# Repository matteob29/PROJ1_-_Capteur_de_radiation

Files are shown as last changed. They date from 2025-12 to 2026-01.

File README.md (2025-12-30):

# PROJ1 – Conception d’un capteur de radiation avec tube Geiger

Projet réalisé dans le cadre du module **PROJ1 – Projet analogique** en première année à l’**ENSEIRB-MATMECA**.

**Auteurs :** 

Mattéo BINET  
Quentin MARIE  

**Date :** 30 décembre 2025  

---

## 1. Introduction

Le projet de conception électronique consiste en l'étude et la réalisation d'un capteur de radiation fonctionnel et compact. Ce système repose sur l'utilisation d'un tube Geiger-Müller J315 pour la détection de particules ionisantes.

L'architecture du circuit est une adaptation modernisée du module CAJOE, transposée en technologie de composants montés en surface (CMS) afin de réduire l'encombrement global. La conception a été intégralement réalisée sous le logiciel de CAO **KiCad E.D.A. 9.0.5**.

---

## 2. Cahier des charges (Tube J315)

- **Type de tube :** Halogène à impulsion pour rayonnements beta et gamma.
- **Tension de travail recommandée :** 380 V.
- **Plage du plateau :** 80 V avec une pente maximale de 10 % / 80 V.
- **Tension d'alimentation :** +5 V DC.
- **Protection :** Fusible de 750 mA intégré pour prévenir les courts-circuits.
- **Consommation nominale :** Environ 40 mA.

---

## 3. Conception du circuit

Le circuit est divisé en quatre blocs fonctionnels principaux :

1. **Module d'Alimentation :**
   - Entrée via connecteur JST XH à trois broches (GND, INT, +5 V).
   - Protection par fusible F1 et filtrage par condensateur de découplage C1 (100 nF).
   - Interrupteur bipolaire SW1 pour la mise hors tension complète.

2. **Étage Boost DC-DC :**
   - Oscillateur basé sur un circuit intégré **NE555** (U1) configuré en mode astable.
   - Élévation de tension par découpage via une inductance L2 (10 mH) et un transistor haute tension **MMBTA42** (Q1).
   - Fréquence d'oscillation fixée à 7059 Hz.

3. **Tripleur de tension :**
   - Structure de type Cockcroft-Walton composée de trois diodes **ES1J** (D2, D3, D4) et de condensateurs haute tension (10 nF / 1000 V).
   - Permet d'atteindre la tension de polarisation théorique de 400 V par effet de pompe de charge.

4. **Détecteur d’impulsion :**
   - Le tube V1 génère une avalanche électronique lors du passage d'une particule.
   - Mise en forme du signal par un second **NE555** (U2) configuré en monostable pour produire une impulsion calibrée de 517 us.
   - Signalisation visuelle par une LED rouge D5 à chaque détection.

---

## 4. Résultats expérimentaux

Les mesures effectuées à l'oscilloscope valident le comportement théorique :

- **Sortie Boost :** Observation de pics de tension d'environ 280 V au nœud boost_dc.
- **Sortie Multiplicateur :** Stabilisation de la haute tension après l'étage de filtrage.
- **Plage de réglage :** Tension de sortie ajustable entre 200 V et 550 V via le potentiomètre RV1, permettant un calage précis à 380 V.

---

## 5. Procédure de réglage

Le réglage de la haute tension s'effectue impérativement sans le tube Geiger :

1. **Mise sous tension :** Alimenter la carte en +5 V et vérifier l'allumage de la LED verte D1.
2. **Mesure :** Placer un voltmètre (calibre 1000 V) entre le point de test "tripleur" et la masse.
3. **Ajustement :** Régler RV1 jusqu'à obtenir 380 V.
4. **Alternative :** Une mesure indirecte est possible au point de test TP_Geiger situé après un pont diviseur de 50 MOhm.

---

## 6. Conclusion

Ce projet a permis de valider la conception d'un compteur Geiger CMS performant. L'intégration des étages de puissance et de détection sur un PCB compact répond aux exigences de fiabilité et de sécurité fixées initialement. Le dispositif constitue une base documentée pour toute application de surveillance radiologique.

---

## 7. Contenu du dépôt GitHub

Le dépôt contient l'intégralité des fichiers nécessaires à la reproduction du projet :

- [Carte_électronique/](./Carte_électronique) -> Schématics, fichiers de routage PCB et modèles 3D Kicad
- [Composants/](./Composants) -> Lien des sites utiles
- [Datasheet/](./Datasheet) -> Fiches techniques des composants critiques (NE555, MMBTA42, J315)
- [code_J315/](./code_J315) -> Exemple de code Arduino pour le comptage des impulsions (PPS)
- [README.md](./README.md) -> Présentation du projet

---

© 2025 — Mattéo BINET, Quentin MARIE
Département Électronique — PROJ1
Enseirb-Matmeca — Capteur de rayonnement beta & gamma

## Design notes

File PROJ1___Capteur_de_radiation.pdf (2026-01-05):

# Capteur de radiation avec tube Geiger

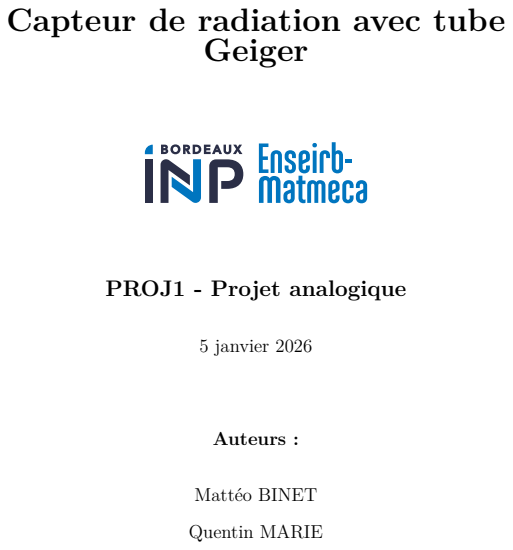
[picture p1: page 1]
PROJ1 - Projet analogique; 5 janvier 2026; Auteurs :; Mattéo BINET; Quentin MARIE

## Sommaire

Introduction | 1
1 Principe de la détection de radiation | 1
2 Étude et conception du circuit | 4
3 Étude et conception du circuit | 8
4 Conclusion | 15
Annexe | 16
Bibliographie | 22

Capteur de radiation avec tube Geiger

## Introduction

La détection des rayonnements ionisants est un enjeu majeur dans de nombreux domaines, allant de la surveillance environnementale à la sécurité nucléaire, en passant par la physique médicale. Dans le cadre de ce projet, nous nous sommes attachés à l’étude, la conception et la réalisation d’un capteur de radiation (compteur Geiger-Müller) fonctionnel et compact.
Pour la conception électronique. Nous avons choisi d’analyser et d’adapter l’architecture du kit CAJOE en cms. L’enjeu technique a consisté à comprendre les différents blocs de ce système, notamment la gestion de la Haute Tension nécessaire au tube pour ensuite proposer notre propre implémentation.
Le travail a été réalisé sous le logiciel de CAO KiCad. Il a fallu saisir le schématique, choisir des composants adaptés et réaliser le routage de la carte en respectant les contraintes de place et de routage.
Ce compte rendu détaille notre démarche : il présente d’abord le principe physique du tube Geiger J315, puis l’analyse du schéma électronique inspiré du module CAJOE, et enfin la description technique des différents étages de la carte réalisée.

## 1 Principe de la détection de radiation

### 1.1 Rôle d’un tube Geiger

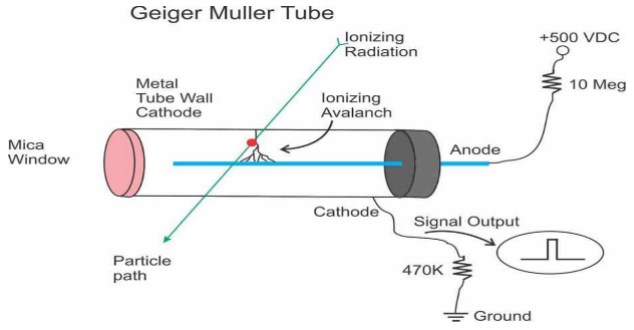
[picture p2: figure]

Figure 1 – Schématique de principe et fonctionnement du tube Geiger-Müller

Le capteur de radiation utilise un tube Geiger-Müller. Ce tube est une ampoule scellée qui contient un gaz inerte à basse pression (typiquement un gaz noble comme du néon, de l’argon ou de l’hélium). Sa structure se compose d’une cathode (pôle négatif), généralement l’enveloppe du tube (verre), et d’une anode (pôle positif), constituée d’un fil métallique fin tendu au centre.
Le principe de fonctionnement repose sur l’ionisation par choc du gaz interne. Afin que la détection soit possible, le tube doit être alimenté par un fort potentiel (typiquement entre 300V et 400V). Les particules radioactives n’ayant pas toujours l’énergie suffisante pour ioniser le gaz par elles-mêmes, cette haute tension est nécessaire pour amener le gaz proche de son point de décharge.
Mattéo BINET | 1 | Quentin MARIE

Lorsqu’une particule chargée (rayonnement ionisant) traverse le tube, elle déclenche l’événement en arrachant des électrons aux atomes du gaz. Ces électrons sont fortement accélérés vers l’anode par le champ électrique intense. Sur leur chemin, leur vitesse leur permet d’entrer en collision avec d’autres atomes, les ionisant à leur tour et arrachant de nouveaux électrons. Ce phénomène se répète en cascade, créant une avalanche électronique massive et rapide. L’arrivée de cette vague d’électrons sur l’anode provoque une chute momentanée du potentiel. Cette variation est détectée sous la forme d’une impulsion électrique, qui est ensuite comptabilisée par l’électronique de la carte.

### 1.2 Caractéristiques du tube J315

Les spécifications suivantes pour le tube Geiger J315 sont extraites du référentiel GitHub du fabricant de la carte et d’un vendeur Aliexpress [1], aucune fiche technique officielle du fournisseur n’ayant été trouvée.

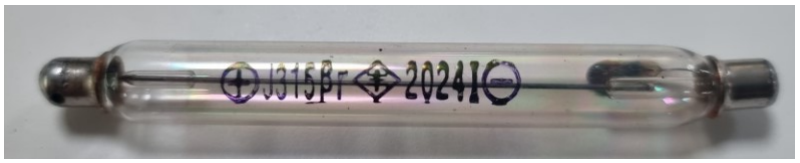
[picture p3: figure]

Figure 2 – Tube Geiger J315

Table 1 – Caractéristiques Techniques Détaillées du Tube Geiger J315

Paramètre | Valeur | Unité
Construction et Dimensions
Type de Tube | Tube halogène à impulsion | –
Matériau de la Cathode | Oxyde d’étain | –
Densité de la Paroi du Tube | 50 ± 10 | cg/cm²
Longueur Totale | 90 ± 2 | mm
Diamètre | 10 ± 0.5 | mm
Masse | 4.5 | g
Performances et Environnement
Plage de Température | −40 à 55 | ◦C
Tension de Démarrage (Vb1 ) | < 350 | V
Tension de Travail Recommandée | 380 | V
Tension de Travail Maximale (Vb2 ) | 550 | V
Longueur Minimale du Plateau | 80 | V
Pente Maximale du Plateau | 10 | %/80V
Taux de Comptage de Fond Max. | 25 | fois/minute
Durée de Vie (Lifetime) | > 1 × 10⁹ | pulses
Mattéo BINET | 2 | Quentin MARIE

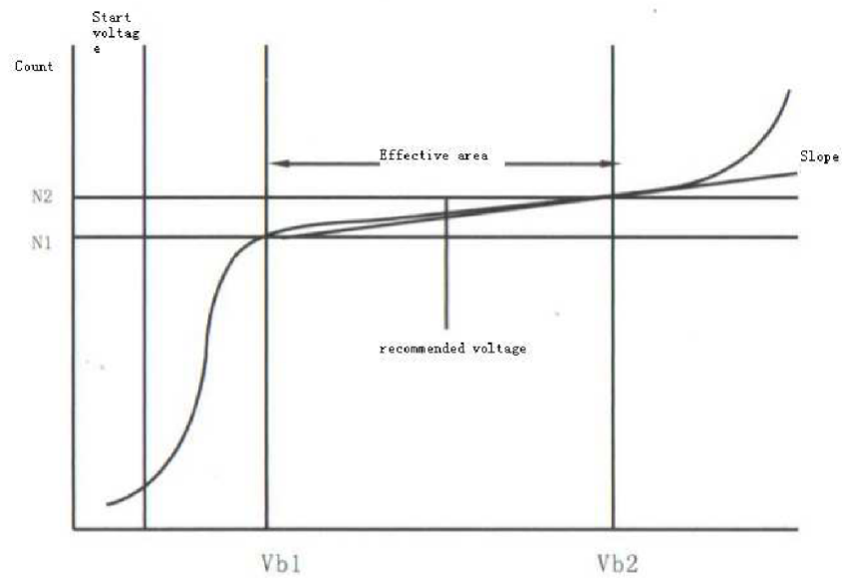
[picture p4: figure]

Figure 3 – Courbe Caractéristique du Plateau

Le graphique en Figure 2 permet de déterminer la tension de travail optimale et stable de notre tube Geiger. Il représente la relation entre le nombre d’impulsions détectées (axe vertical) et la tension appliquée au tube (axe horizontal).

— Tension de Démarrage (Vb1) : Cette tension correspond à la tension minimale où le tube commence à détecter les rayonnements, initiant l’avalanche électronique. Avant cette tension, le champ électrique est insuffisant pour accélérer les électrons.
— Le Plateau (Effective Area) : Situé entre la tension Vb1 et Vb2, il s’agit de la zone de fonctionnement idéale du tube. Dans cette région, l’impulsion détectée est maximale et ne dépend plus de l’énergie de la particule incidente. C’est dans cette plage stable que la tension d’alimentation doit être choisie (Tension de Travail Recommandée).

— La Pente (Slope) : Elle représente la stabilité du tube. Une pente faible indique que le taux de détection est peu sensible aux variations de la tension d’alimentation. — Tension Maximale de Travail (Vb2) : Cette tension marque la limite supérieure du plateau. Au-delà de Vb2, le champ électrique est trop intense et le tube entre en décharge continue car le gaz s’ionise spontanément. Le fonctionnement dans cette zone peut dégrader le tube de manière permanente.

Mattéo BINET | 3 | Quentin MARIE

## 2 Étude et conception du circuit

### 2.1 Architecture du module CAJOE

Le module CAJOE [2] est une plateforme de détection de radiation. Nous l’avons choisi comme référence car il propose une solution robuste et entièrement analogique pour piloter des tubes Geiger-Müller, sans nécessiter de microcontrôleur complexe pour la gestion de la haute tension.
Son architecture s’articule autour de trois blocs fonctionnels distincts, que nous avons reproduits dans notre conception :

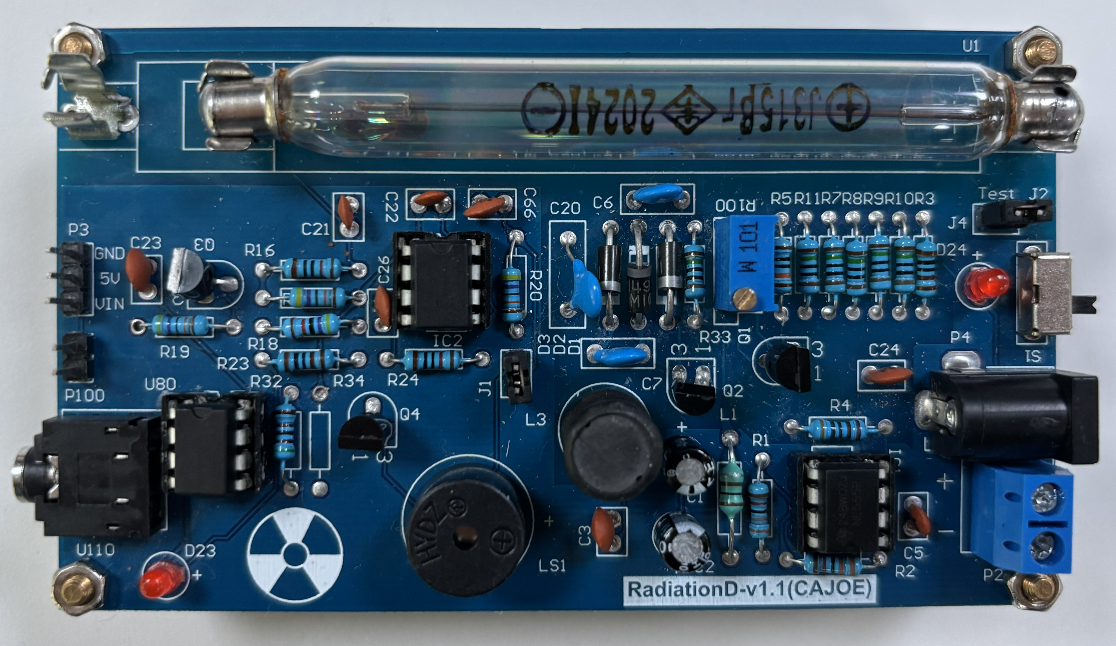
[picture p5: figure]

Figure 4 – Carte électronique du détecteur CAJOE

— La génération de Haute Tension (HV) : Le tube J315 nécessite une tension de polarisation d’environ 400V pour fonctionner dans sa zone de plateau. Le module CAJOE utilise une topologie de convertisseur Boost (élévateur de tension) pilotée par un oscillateur composé d’un NE555. Ce premier étage élève la tension de 5V à une centaine de volts. Cette tension est ensuite amplifiée par un réseau tripleur de tension (pompe de charge) pour atteindre la tension finale requise. La tension de sortie est réglable via le potentiomètre RV1 de 100Ω. Il permet d’ajuster la haute tension sur une plage comprise entre 350V et 450V , assurant ainsi le point de fonctionnement optimal du tube.

— L’interface de détection : Le tube Geiger est un capteur à très haute impédance. Lorsqu’une particule ionise le gaz, une impulsion de courant très faible et brève est générée. L’architecture utilise un étage d’entrée à transistor pour détecter cette variation de potentiel sur la cathode sans perturber la haute tension.

— La mise en forme du signal : Le signal brut issu du tube est souvent bruité et trop court pour être exploité directement par un indicateur visuel. Un étage de sortie, configuré en monostable via un second NE555, permet de calibrer l’impulsion de sortie. Cela garantit un signal carré propre (TTL) d’une durée suffisante pour qu’une LED rouge (témoin lumineux) soit visible par l’œil humain.

Mattéo BINET | 4 | Quentin MARIE

### 2.2 Fonctionnement et utilisation de la carte CMS

Cette version du capteur se distingue des modules CAJOE classiques par une conception modernisée et simplifiée.

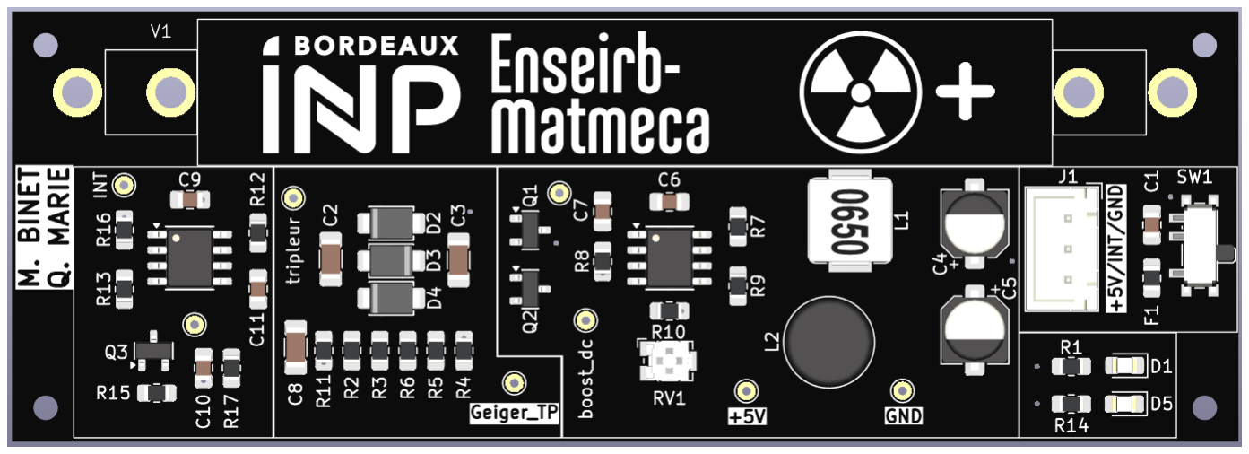
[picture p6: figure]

Figure 5 – Modèle 3D - Carte électronique CMS

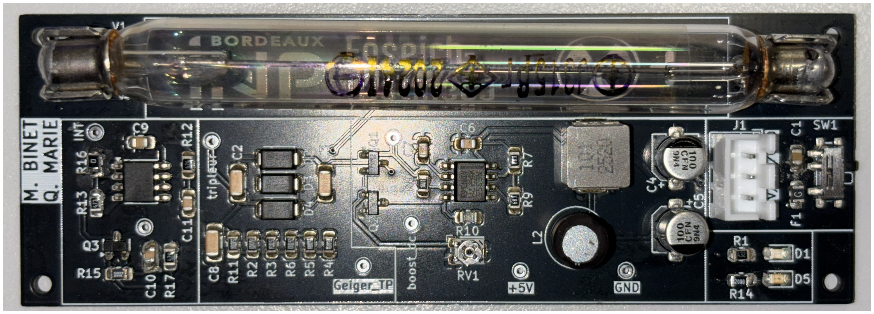
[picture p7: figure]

Figure 6 – Carte électronique CMS

### 2.2.1 Sécurité et Protection

Un ajout majeur par rapport au design d’origine est l’intégration d’un étage de protection en entrée. Un fusible F1 a été placé en série sur la ligne d’alimentation 5V. Il est calibré à 750mA. Ce dimensionnement est volontairement supérieur à la consommation nominale du circuit (≈ 40mA) afin d’éviter tout déclenchement intempestif lors des pics de courant, tout en garantissant une protection efficace et une coupure du circuit en cas de court-circuit franc sur la carte.

### 2.2.2 Comparatif : Module CAJOE vs Carte CMS

Le tableau ci-dessous met en évidence les différences structurelles et fonctionnelles entre le module du commerce et notre réalisation.

Mattéo BINET | 5 | Quentin MARIE

Table 2 – Comparaison entre le module CAJOE standard et la carte CMS réalisée

Caractéristique | Module CAJOE (Réf) | Carte CMS (Projet)
Technologie | THT | CMS
Connectique | Bornier, DC, Dupont | JST XH 3 pins
Interface Audio | Jack 3.5mm + Haut-parleur | Ø
Protection | Ø | Fusible 750mA
Architecture | AOP LM358 + NE555 | NE555 uniquement
Tension d’alimentation | +5V | +5V
Courant nominal d’alimentation | 20-40mA | 20-40mA
Poids avec tube | 47.3g | 19.0g
Longueur | 108mm | 100mm
Largeur | 62, 8mm | 35mm
trou de fixation | M3 | M2

### 2.2.3 Procédure de réglage

Le réglage de la haute tension est une étape critique qui doit être réalisée avant l’installation du tube.

1. Préparation : S’assurer que le tube Geiger J315 est débranché de son support.
2. Alimentation : Connecter l’alimentation (+5V et GND) au connecteur JST. Une LED verte (D1 : témoin d’alimentation) doit normalement s’allumer. Si ce n’est pas le cas, vérifier que le kill switch (SW1) est en position haute.

Méthodes de calibration : Il existe deux méthodes pour ajuster le potentiomètre RV1 afin d’atteindre la tension de plateau du tube (380V).

— Méthode 1 : Mesure directe
Cette méthode consiste à mesurer la tension réelle en sortie du multiplicateur.
— Placer le voltmètre (calibre 1000V DC) entre la masse (GND) et le point de test tripleur.
— Ajuster RV1 jusqu’à lire 380V.
— Attention : S’assurer que le multimètre supporte cette tension élevée.

— Méthode 2 : Mesure indirecte
Cette méthode utilise le point de test TP_Geiger (ou TP3) situé après un pont diviseur résistif de 50MΩ (5×10MΩ). La lecture dépendra fortement de l’impédance d’entrée de votre multimètre (effet de charge) :

— Avec un multimètre standard (impédance 1 MΩ) : Régler RV1 pour obtenir environ 6,5V.
— Avec un multimètre haute impédance (impédance 10 MΩ) : Régler RV1 pour obtenir environ 65V.

Une fois le réglage effectué, couper l’alimentation avant d’insérer le tube J315.

Mattéo BINET | 6 | Quentin MARIE

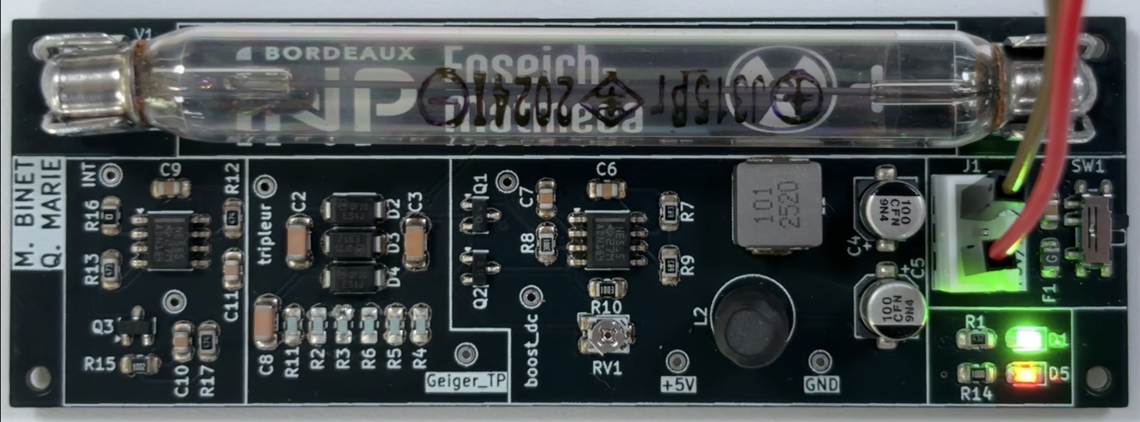
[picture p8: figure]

Figure 7 – Carte électronique en fonctionnement

### 2.3 Utilisation

Le capteur de radiation peut être exploité de deux manières. D’une part, les données peuvent être récupérées via une carte d’acquisition telle qu’une Arduino ou une ESP, en utilisant la broche INT disponible sur le connecteur JST. Cette sortie est maintenue à un niveau logique haut (environ 5 V) au repos et génère une impulsion à 0 V à chaque détection d’une particule par le tube Geiger J315. Le signal étant actif bas, il peut être lu efficacement à l’aide d’une interruption matérielle afin de compter précisément les événements détectés.
Un exemple de code utilisé pour compter le nombre d’impulsions détectées sur la dernière seconde (PPS – Pulses Per Second) à l’aide d’une carte Arduino Nano est présenté ci-dessous.

Listing 1 – Comptage des impulsions Geiger en PPS

# define GEIGER_PIN 2

volatile unsigned long pulseCount = 0; unsigned long lastSecond = 0; unsigned long pps = 0;

void geigerISR () {
pulseCount ++;

}

void setup () {
Serial . begin (115200) ;
while (! Serial ) ;

pinMode ( GEIGER_PIN , INPUT_PULLUP ) ;
attachInterrupt ( digitalPinToInterrupt ( GEIGER_PIN ) , geigerISR , FALLING ) ;

lastSecond = millis () ;

}

void loop () {

Mattéo BINET | 7 | Quentin MARIE

23 if ( millis () - lastSecond >= 1000) {

24
25 | noInterrupts () ;
26 | pps = pulseCount ;
27 | pulseCount = 0;
28 | interrupts () ;

29
30 | Serial . print ("PPS = ") ;
31 | Serial . println ( pps ) ;

32
33 | lastSecond += 1000;
34 | }
35 | }

D’autre part, la carte intègre une LED rouge (D5) permettant de visualiser les détections de manière immédiate. Chaque événement déclenche une impulsion lumineuse, facilitant la vérification du bon fonctionnement du capteur. Toutefois, cette LED est pilotée par un NE555 configuré en monostable, ce qui impose une durée d’allumage fixe. Ainsi, le nombre d’impulsions lumineuses observées n’est pas représentatif du nombre réel d’impulsions générées par le tube Geiger et ne doit être utilisé qu’à titre indicatif.

## 3 Étude et conception du circuit

### 3.1 Module d’Alimentation

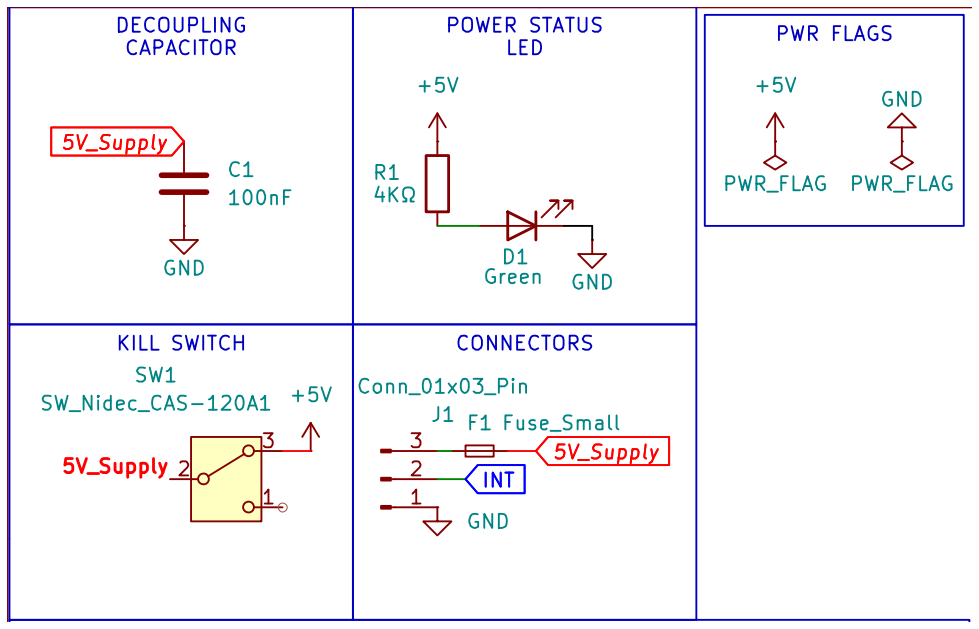
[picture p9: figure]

Figure 8 – Schématique du module d’alimentation

Dans le cadre de notre montage, nous utilisons un connecteur JST XH à trois broches : une pour la masse (GND), une pour la sortie des impulsions générées par le tube Geiger, et une pour l’alimentation +5V. Pour protéger le circuit, un fusible est placé en série

Mattéo BINET | 8 | Quentin MARIE

sur la ligne 5V afin d’interrompre l’alimentation en cas de surintensité. À proximité de l’entrée d’alimentation, nous avons intégré une capacité de découplage de 100nF dont le rôle est de filtrer les parasites hautes fréquences et de stabiliser la tension d’entrée.
Afin de confirmer visuellement la mise sous tension, une LED verte témoin s’allume dès que la carte est alimentée. Enfin, un interrupteur bipolaire permet de couper physiquement l’alimentation de l’ensemble du système pour garantir une mise hors tension complète.

### 3.2 Boost DC-DC

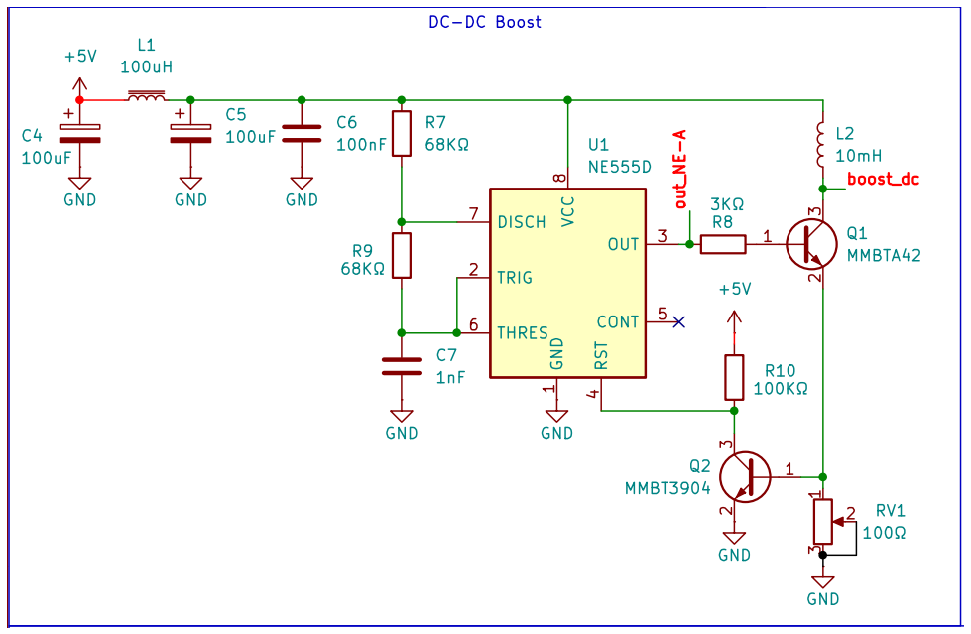
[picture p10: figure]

Figure 9 – Schématique du boost DC-DC

À la suite du module d’alimentation, un convertisseur Boost DC-DC permet d’élever la tension de 5V vers une tension de plusieurs centaines de volts, nécessaire au fonctionnement du tube Geiger. Le cœur de ce circuit repose sur un circuit intégré NE555 [3] configuré en mode astable. Le NE555 génère un signal oscillant entre deux phases : une phase d’accumulation d’énergie et une phase de transfert. La fréquence d’oscillation f est déterminée par les résistances R7,R9 et le condensateur C7 selon la formule suivante :

f =

1.44
(R7 + 2R9)C7
= 7059Hz | (1)

La durée de la phase d’accumulation, correspondant à l’état haut du signal (Th), se calcule ainsi :

| Th = 0.693(R7 + R9)C7 = 94µs | (2)

Le temps de transfert, correspondant à l’état bas (Tb), est donné par :

| Tl = 0.693R9C7 = 47µs | (3)

Le découpage de la tension s’effectue par l’interaction entre l’inductance L7 et le transistor de puissance Q1 [4]. Lorsque le signal de sortie du NE555 est à l’état haut, le

Mattéo BINET | 9 | Quentin MARIE

transistor Q1 devient passant. Le courant traverse alors l’inductance L2 (10mH), stockant l’énergie sous forme de champ magnétique. Lorsque Q1 se bloque brutalement, l’inductance s’oppose à l’interruption du courant et génère une forte pointe de tension (surtension inductive) au nœud boost_dc.
Afin d’éviter que le bruit généré par ce découpage ne perturbe le reste du circuit, un filtre en entrée est réalisé par les condensateurs C4,C5,C6 et l’inductance L1. Enfin, la stabilisation et l’ajustement de la tension de sortie sont assurés par le transistor Q2 [5] et le potentiomètre RV1. Ce dernier permet de régler précisément le point de fonctionnement pour caler la haute tension sur la valeur recommandée du tube Geiger.

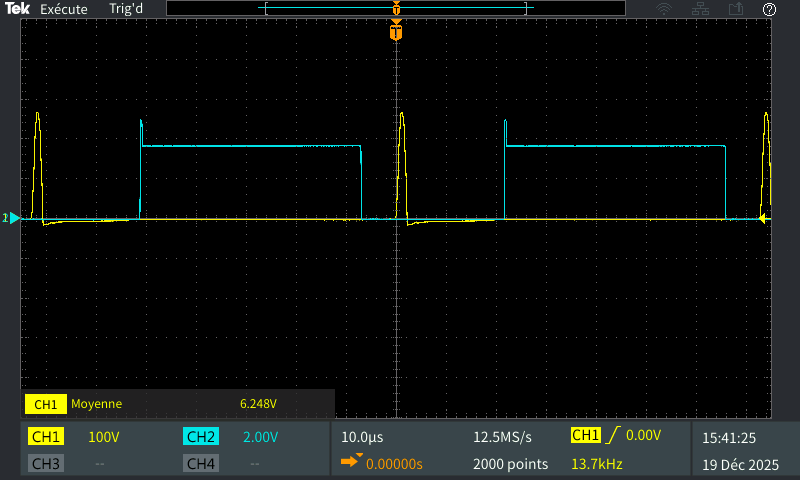
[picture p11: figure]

Figure 10 – CH1 : VboostDC et CH2 : VoutNE−A :

En plaçant une sonde d’oscilloscope au nœud boost_dc, on observe des pics de tension d’une amplitude d’environ 280 V. Ces pics correspondent à la surtension inductive générée par l’inductance L2 lors du blocage du transistor Q1. Cette valeur confirme le bon fonctionnement de l’étage élévateur, fournissant une base de tension suffisante pour être ensuite traitée par le tripleur de tension.

Mattéo BINET | 10 | Quentin MARIE

### 3.3 Tripleur de tension

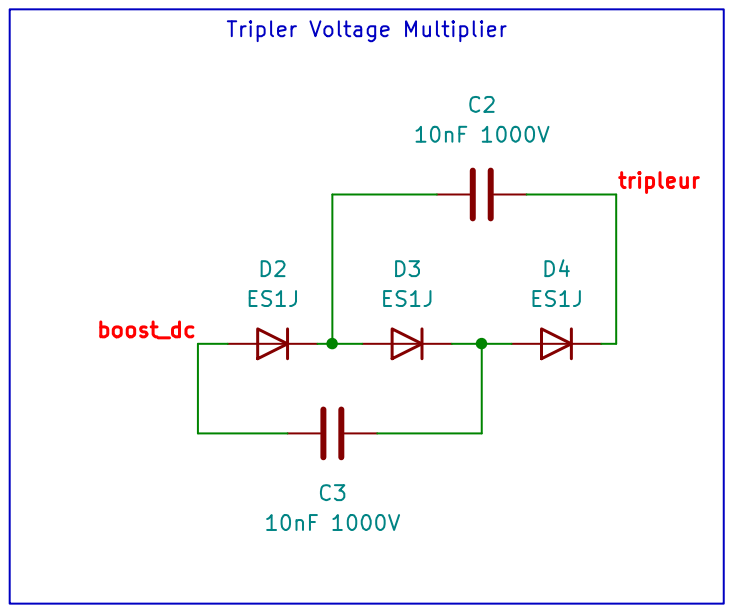
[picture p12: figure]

Figure 11 – Schématique du tripleur de tension

Pour élever la tension de sortie du NE555 jusqu’aux valeurs requises par le tube, nous utilisons un tripleur de tension. Ce montage permet de transformer les impulsions de tension (pics inductifs) générées par le bloc Boost en une tension continue stabilisée et nettement plus élevée.
Le circuit adopte une structure de type Cockcroft-Walton, constituée des éléments suivants :
— Condensateurs : C2 et C3 [6] d’une capacité de 10 nF.

— Diodes : Trois diodes haute tension de référence ES1J [7].
À chaque cycle d’oscillation du NE555, l’énergie des pics inductifs est transférée d’un condensateur à l’autre par un effet de pompe de charge. Les diodes agissent comme des clapets anti-retour, empêchant la décharge des condensateurs vers l’amont et permettant l’addition de leurs tensions respectives.
En sortie, on obtient ainsi une tension théoriquement trois fois supérieure à la tension de crête d’entrée. Ces condensateurs haute tension assurent également le lissage de la tension continue afin d’éliminer les ondulations résiduelles (ripple), évitant ainsi les fausses détections ou le bruit de fond au niveau du tube.
Dans des conditions idéales, sans courant de sortie, la tension continue Vout est un multiple direct de la tension de crête d’entrée Vpk. Pour un montage à n étages (ici n = 3), la relation s’écrit :
Vout = n · Vpk | (4)
Mattéo BINET | 11 | Quentin MARIE

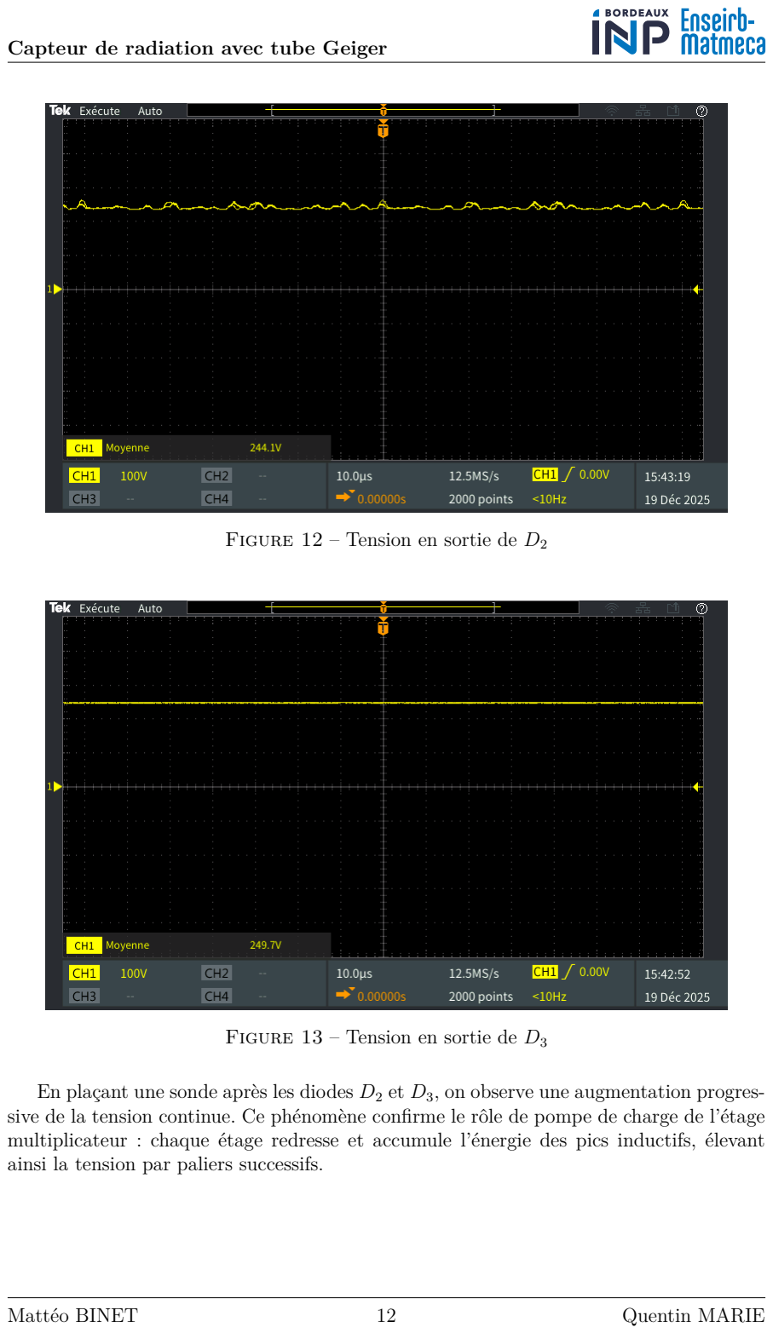
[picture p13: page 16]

Figure 12 – Tension en sortie de D2

Figure 13 – Tension en sortie de D3

En plaçant une sonde après les diodes D2 et D3, on observe une augmentation progressive de la tension continue. Ce phénomène confirme le rôle de pompe de charge de l’étage multiplicateur : chaque étage redresse et accumule l’énergie des pics inductifs, élevant ainsi la tension par paliers successifs.

Mattéo BINET | 12 | Quentin MARIE

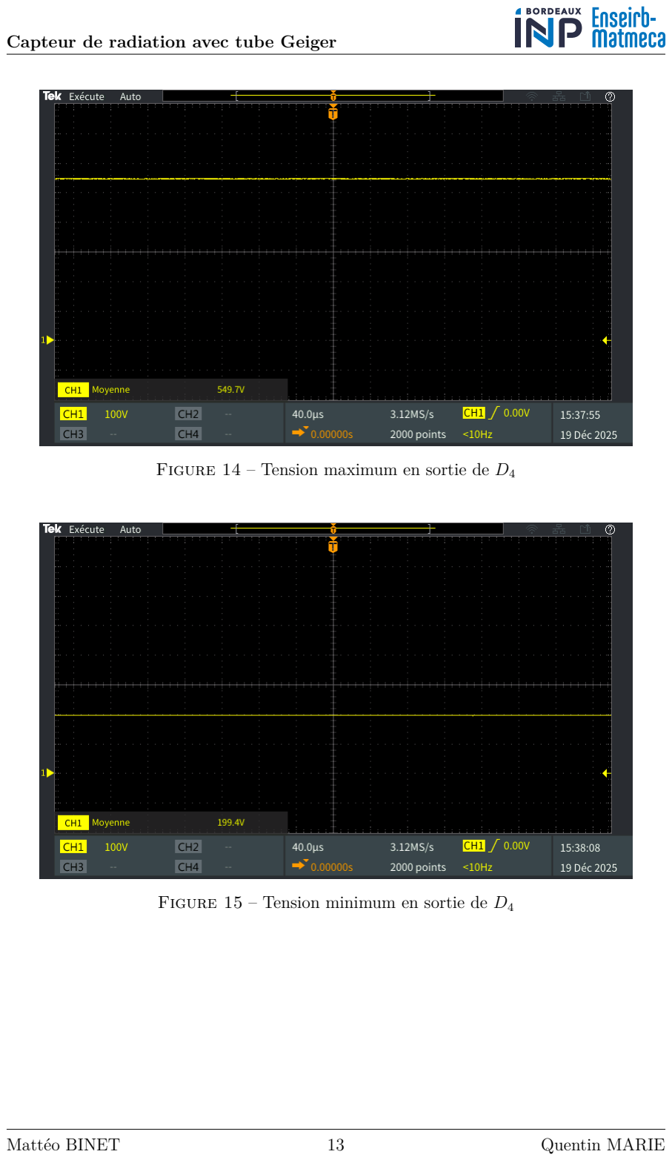
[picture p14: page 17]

Figure 14 – Tension maximum en sortie de D4

Figure 15 – Tension minimum en sortie de D4

Mattéo BINET | 13 | Quentin MARIE

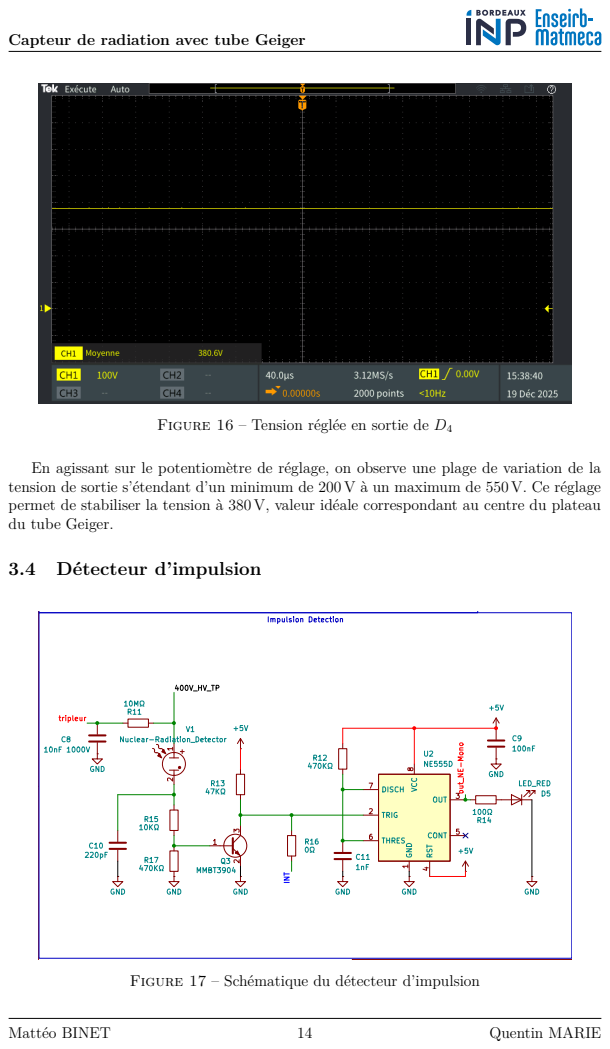
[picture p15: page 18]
3.4 Détecteur d’impulsion; Mattéo BINET; Quentin MARIE

Figure 16 – Tension réglée en sortie de D4

En agissant sur le potentiomètre de réglage, on observe une plage de variation de la
tension de sortie s’étendant d’un minimum de 200 V à un maximum de 550 V. Ce réglage
permet de stabiliser la tension à 380 V, valeur idéale correspondant au centre du plateau
du tube Geiger.

Figure 17 – Schématique du détecteur d’impulsion

Le dernier bloc de notre circuit assure la détection des impulsions. En sortie du tube Geiger, le condensateur C10 bloque la composante continue de haute tension tout en laissant passer la variation rapide créée par l’avalanche électronique.
Le signal sortant du tube, caractérisé par un faible courant, arrive sur la base du transistor Q3, le rendant passant durant un très court instant. La sortie INT reliée au connecteur XH passe donc à la masse pendant ce court instant. Dans le même temps, la broche Trigger du NE555 est alors reliée à la masse, ce qui déclenche le cycle de chronométrage du circuit.
Le NE555 (U2), configuré en mode monostable, transforme ce signal brut très rapide en une impulsion carrée. La durée de cette impulsion est définie par l’équation suivante :
Tw = 1.1 · R12C11 = 517µs | (5)

La sortie du NE555 est reliée à une LED qui la fait clignoter à chaque impulsion détectée pour offrir un retour visuel à l’utilisateur.
En sortie du circuit, le clignotement de la LED à chaque détection confirme que le système fonctionne correctement. À l’oscilloscope, on visualise des impulsions propres dont la tension varie entre 0V et une valeur inférieure à 5V. Ces signaux bien calibrés prouvent que le circuit réussit à transformer les décharges du tube en impulsions numériques utilisables par un microcontrôleur.

## 4 Conclusion

Ce projet a permis de concrétiser l’étude et la réalisation d’un compteur Geiger-Müller compact, optimisé pour la détection des rayonnements β et γ via le tube J315. En faisant évoluer l’architecture analogique du module CAJOE vers un design CMS modernisé, nous avons pu intégrer des fonctions de protection indispensables, comme le fusible de 750mA, tout en réduisant considérablement l’encombrement de la carte. Les mesures expérimentales ont validé la fiabilité de chaque étage, notamment la stabilité de la haute tension à 380V et la qualité des impulsions numériques générées lors des détections.
Dans une démarche de transparence et de reproductibilité, l’intégralité de la conception réalisée sous KiCad est disponible sur le dépôt GitHub du projet [8]. Pour faciliter la maintenance ou la fabrication de nouvelles unités, la nomenclature exacte des composants est également accessible via une liste dédiée sur DigiKey [9]. Ce dispositif constitue ainsi une base solide et documentée pour toute future application de surveillance radiologique.
Mattéo BINET | 15 | Quentin MARIE

## Annexe

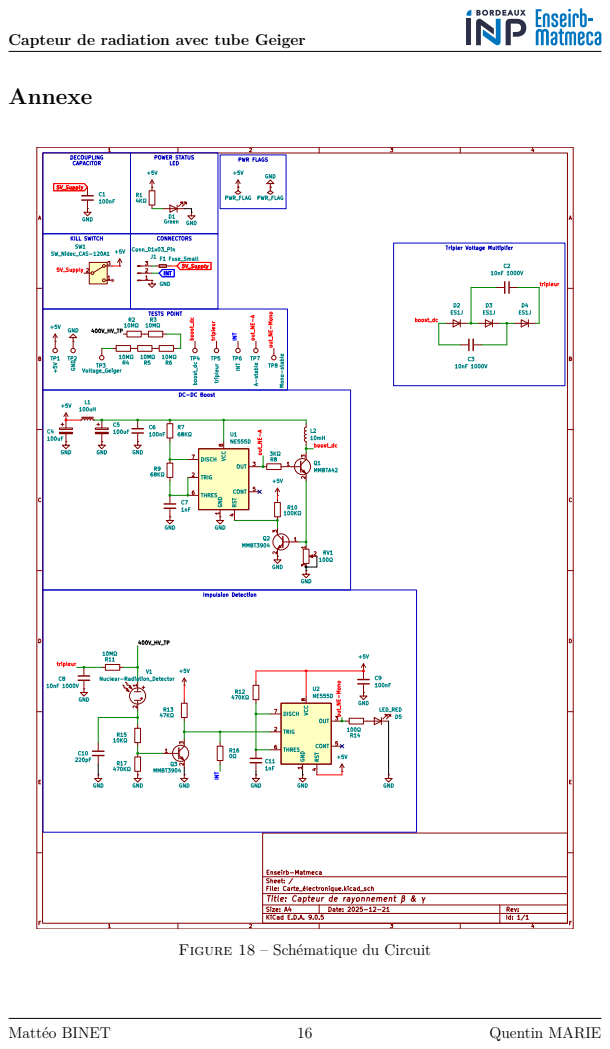
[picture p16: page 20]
Mattéo BINET; Quentin MARIE

Figure 18 – Schématique du Circuit

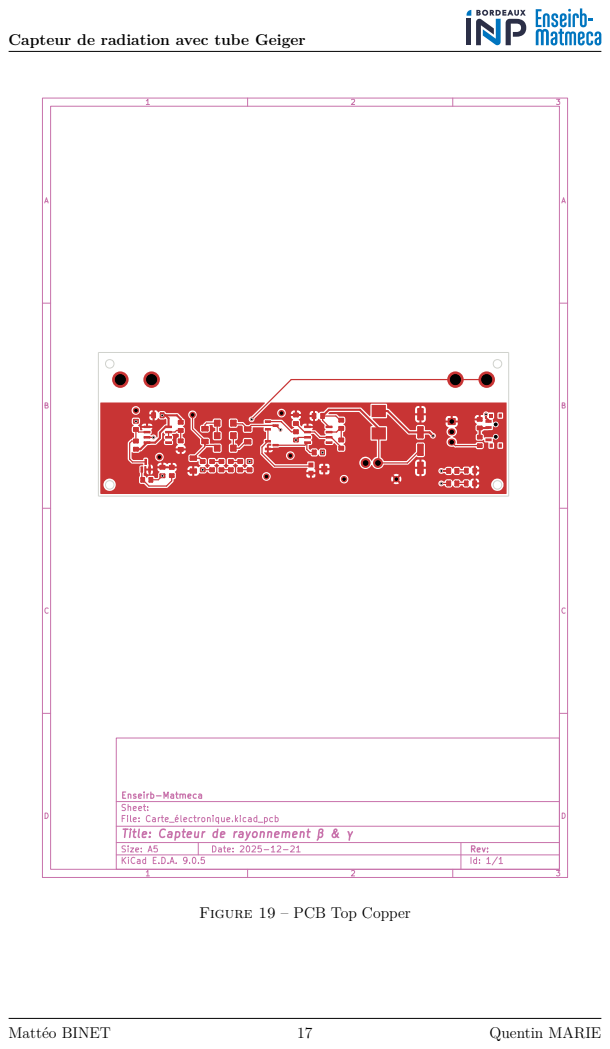
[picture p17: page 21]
Mattéo BINET; Quentin MARIE

Figure 19 – PCB Top Copper

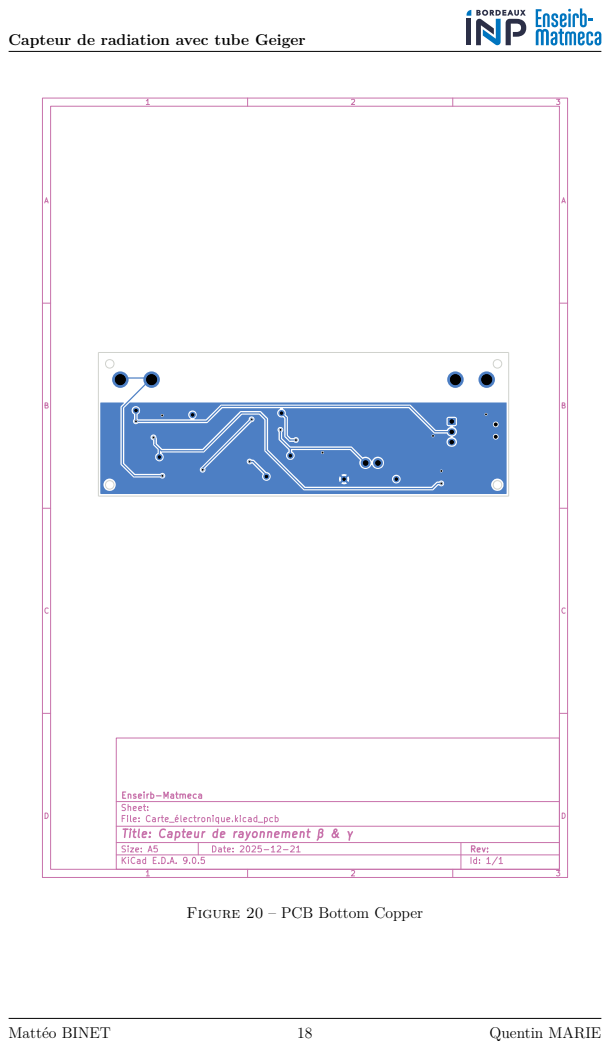
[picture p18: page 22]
Mattéo BINET; Quentin MARIE

Figure 20 – PCB Bottom Copper

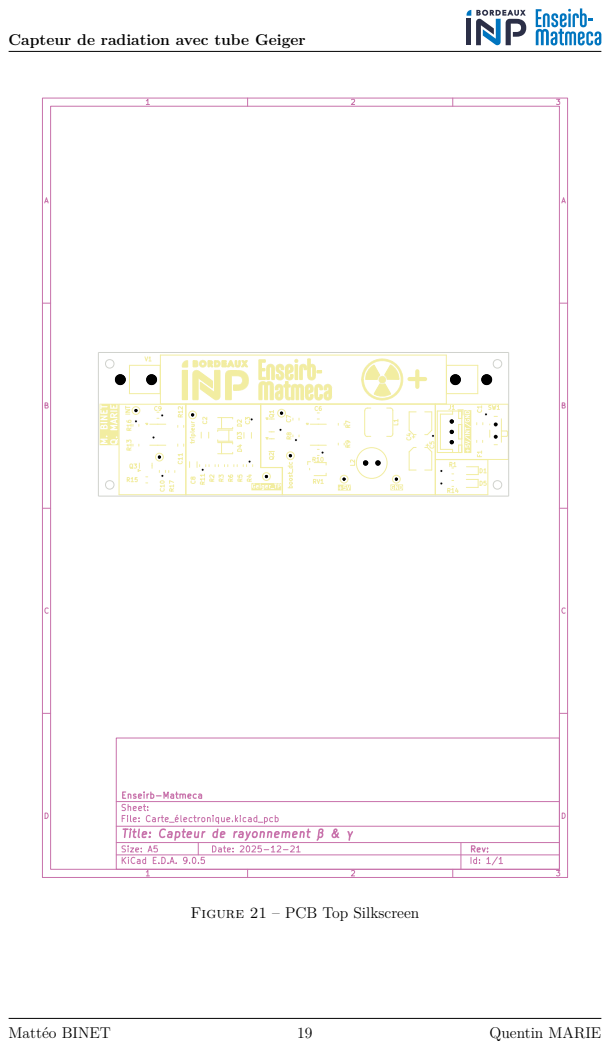
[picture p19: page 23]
Mattéo BINET; Quentin MARIE

Figure 21 – PCB Top Silkscreen

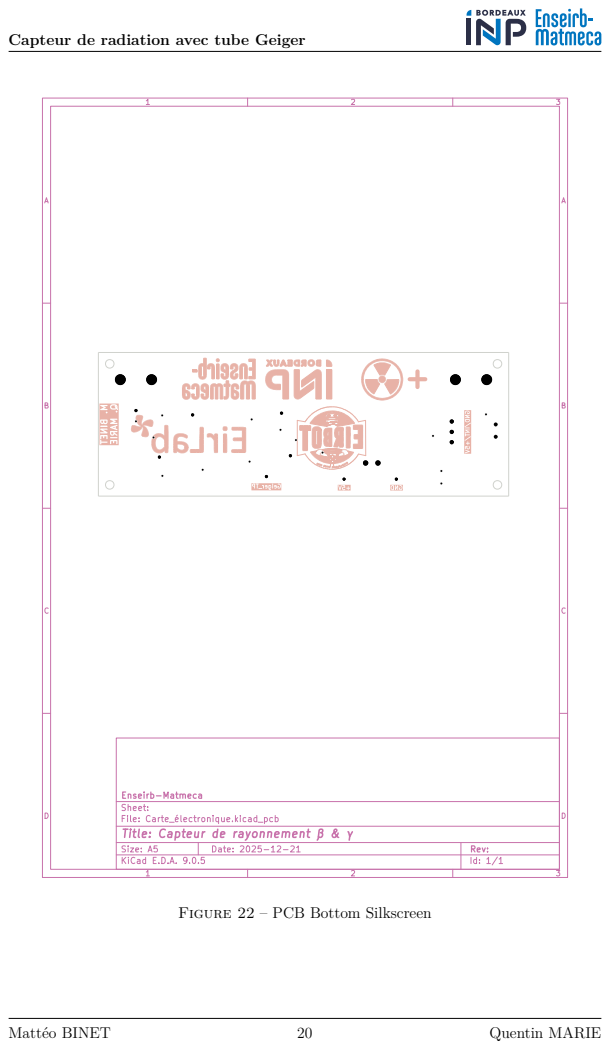
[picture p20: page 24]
Mattéo BINET; Quentin MARIE

Figure 22 – PCB Bottom Silkscreen

Capteur de radiation avec tube Geiger Value | Ref | Footprint | LCSC | Quantity
100nF | C1,C6,C9 | C_0805_2012Metric_Pad1.18x1.45mm_HandSolder | C49678 | 3
220pF | C10 | C_0805_2012Metric_Pad1.18x1.45mm_HandSolder | C107145 | 1
1nF | C11,C7 | C_0805_2012Metric_Pad1.18x1.45mm_HandSolder | C94121 | 2
10nF 1000V | C2,C3,C8 | C_1206_3216Metric_Pad1.33x1.80mm_HandSolder | C9194 | 3
100uF | C4,C5 | CP_Elec_5x5.3 | C445083 | 2
Green | D1 | LED_0805_2012Metric_Pad1.15x1.40mm_HandSolder | C84260 | 1
ES1J | D2,D3,D4 | D_SMAF | C232830 | 3
LED_RED | D5 | LED_0805_2012Metric_Pad1.15x1.40mm_HandSolder | C965812 | 1
Fuse_Small | F1 | Fuse_0805_2012Metric_Pad1.15x1.40mm_HandSolder | C883111 | 1
Conn_01x03_Pin | J1 | JST_XH_B3B-XH-A_1x03_P2.50mm_Vertical | C144394 | 1
100uH | L1 | L_Bourns_SRP7028A_7.3x6.6mm | C2894722 | 1
10mH | L2 | L_Radial_D7.2mm_P3.00mm_Murata_1700 | C5380230 | 1
MMBTA42 | Q1 | D_SOT-23 | C181172 | 1
MMBT3904 | Q2,Q3 | D_SOT-23 | C916374 | 2
4KΩ | R1 | R_0805_2012Metric_Pad1.20x1.40mm_HandSolder | C23179 | 1
100KΩ | R10 | R_0805_2012Metric_Pad1.20x1.40mm_HandSolder | C96346 | 1
10MΩ | R11,R2,R3,R4,R5,R6 | R_0805_2012Metric_Pad1.20x1.40mm_HandSolder | C107700 | 6
470KΩ | R12,R17 | R_0805_2012Metric_Pad1.20x1.40mm_HandSolder | C17709 | 2
47KΩ | R13 | R_0805_2012Metric_Pad1.20x1.40mm_HandSolder | C17713 | 1
100Ω | R14 | R_0805_2012Metric_Pad1.20x1.40mm_HandSolder | C17408 | 1
10KΩ | R15 | R_0805_2012Metric_Pad1.20x1.40mm_HandSolder | C84376 | 1
0Ω | R16 | R_0805_2012Metric_Pad1.20x1.40mm_HandSolder | C17477 | 1
68KΩ | R7,R9 | R_0805_2012Metric_Pad1.20x1.40mm_HandSolder | C2933415 | 2
3KΩ | R8 | R_0805_2012Metric_Pad1.20x1.40mm_HandSolder | C2907263 | 1
100Ω | RV1 | Potentiometer_Bourns_TC33X_Vertical | C911390 | 1
SW_Nidec_CAS-120A1 | SW1 | SW_SPDT_PCM12 | C109335 | 1
NE555D | U1,U2 | SOIC-8_3.9x4.9mm_P1.27mm | C596355 | 2

Figure 23 – BOM du Circuit

Mattéo BINET | 21 | Quentin MARIE

## Bibliographie

### Fiches techniques des composants (Datasheets)

[1] J315 : Tube Geiger-Müller à halogène (β & γ). (https://fr.aliexpress.com/item/32813797514.html) Capteur de radiation ionisante V1. Generic Specification. 2023.
[3] 555 Type, Timer/Oscillator (Single) IC 100kHz 8-SOIC. (https://www.ti.com/lit/ds/symlink/ne555.pdf) Utilisé pour le Boost et le Monostable. Texas Instruments. 2014.
[4] MMBTA42 : Transistor NPN 300V 500mA 50MHz Surface Mount SOT-23-3. (https://diotec.com/request/datasheet/mmbta42.pdf) Transistor de puissance du convertisseur Boost. Diotec Semiconductor. 2025.
[5] MMBT3904 : Transistor NPN 40V 200mA 300MHz Surface Mount SOT-23-3. (https://diotec.com/request/datasheet/mmbt3904.pdf) Régulation et détection d’impulsions. Diotec Semiconductor. 2025.
[6] Capacité céramique : 10nF 1000V 1206 Surface Mount. (https://calchip.com/wp-content/uploads/2023/02/chv_series.pdf) Capacités du tripleur de tension. Cal-Chip Electronics. 2023.
[7] ES1J : Diode 600 V 1A Surface Mount SMA. (https://www.hygroup.com.tw/upfiles/ADUpload/all_/8-ES1A-ES1J(SMA).pdf) Diodes du tripleur de tension. HY Electronic. 2020.

### Documentation de référence

[2] CAJOE Technology. Architecture de référence du module Geiger CAJOE. (https://github.com/SensorsIot/Geiger-Counter-RadiationD-v1.1-CAJOE-/tree/master) 2023.

### Ressources du projet

[8] Dépôt GitHub du projet. (https://github.com/matteob29/PROJ1_-_Capteur_de_radiation) matteo.b29, 2025.
[9] Liste des composants sur DigiKey. (https://www.digikey.at/en/mylists/list/5D192P6EX0) Enseirb-Matmeca, 2025.
Mattéo BINET | 22 | Quentin MARIE

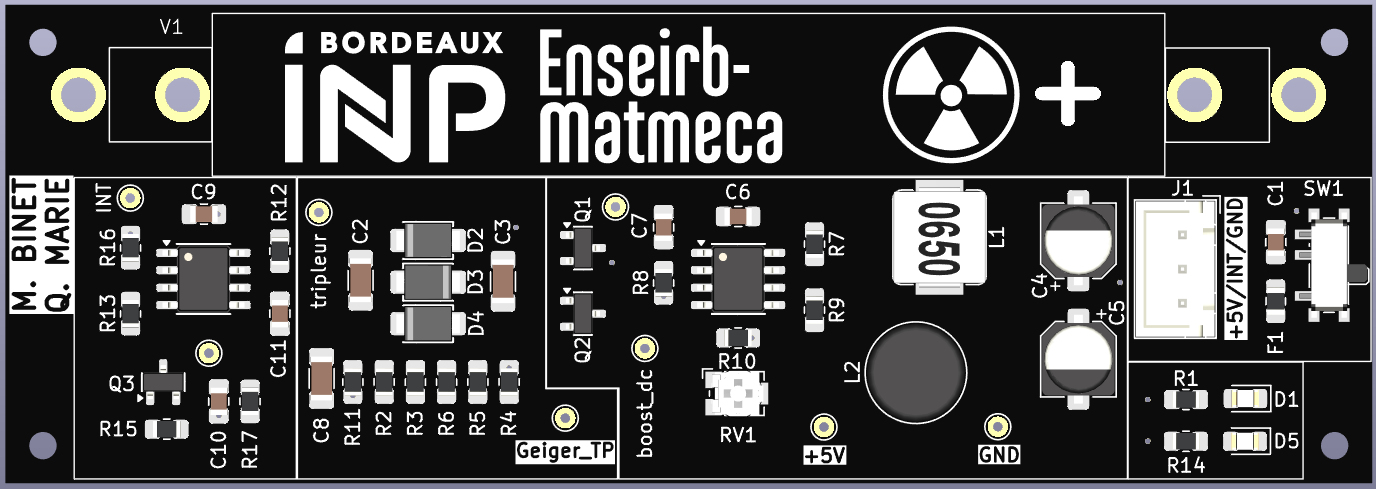
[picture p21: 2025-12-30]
Carte_électronique/3D_Dessus.png

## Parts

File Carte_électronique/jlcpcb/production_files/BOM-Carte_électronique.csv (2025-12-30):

Comment | Designator | Footprint | LCSC | Quantity
220pF | C10 | C_0805_2012Metric_Pad1.18x1.45mm_HandSolder | C107145 | 1
10MΩ | R11,R2,R3,R4,R5,R6 | R_0805_2012Metric_Pad1.20x1.40mm_HandSolder | C107700 | 6
SW_Nidec_CAS-120A1 | SW1 | SW_SPDT_PCM12 | C109335 | 1
Conn_01x03_Pin | J1 | JST_XH_B3B-XH-A_1x03_P2.50mm_Vertical | C144394 | 1
100Ω | R14 | R_0805_2012Metric_Pad1.20x1.40mm_HandSolder | C17408 | 1
0Ω | R16 | R_0805_2012Metric_Pad1.20x1.40mm_HandSolder | C17477 | 1
470KΩ | R12,R17 | R_0805_2012Metric_Pad1.20x1.40mm_HandSolder | C17709 | 2
47KΩ | R13 | R_0805_2012Metric_Pad1.20x1.40mm_HandSolder | C17713 | 1
MMBTA42 | Q1 | D_SOT-23 | C181172 | 1
4KΩ | R1 | R_0805_2012Metric_Pad1.20x1.40mm_HandSolder | C23179 | 1
ES1J | D2,D3,D4 | D_SMAF | C232830 | 3
100uH | L1 | L_Bourns_SRP7028A_7.3x6.6mm | C2894722 | 1
3KΩ | R8 | R_0805_2012Metric_Pad1.20x1.40mm_HandSolder | C2907263 | 1
68KΩ | R7,R9 | R_0805_2012Metric_Pad1.20x1.40mm_HandSolder | C2933415 | 2
100uF | C4,C5 | CP_Elec_5x5.3 | C445083 | 2
100nF | C1,C6,C9 | C_0805_2012Metric_Pad1.18x1.45mm_HandSolder | C49678 | 3
10mH | L2 | L_Radial_D7.2mm_P3.00mm_Murata_1700 | C5380230 | 1
NE555D | U1,U2 | SOIC-8_3.9x4.9mm_P1.27mm | C596355 | 2
Green | D1 | LED_0805_2012Metric_Pad1.15x1.40mm_HandSolder | C84260 | 1
10KΩ | R15 | R_0805_2012Metric_Pad1.20x1.40mm_HandSolder | C84376 | 1
Fuse_Small | F1 | Fuse_0805_2012Metric_Pad1.15x1.40mm_HandSolder | C883111 | 1
100Ω | RV1 | Potentiometer_Bourns_TC33X_Vertical | C911390 | 1
MMBT3904 | Q2,Q3 | D_SOT-23 | C916374 | 2
10nF 1000V | C2,C3,C8 | C_1206_3216Metric_Pad1.33x1.80mm_HandSolder | C9194 | 3
1nF | C11,C7 | C_0805_2012Metric_Pad1.18x1.45mm_HandSolder | C94121 | 2
100KΩ | R10 | R_0805_2012Metric_Pad1.20x1.40mm_HandSolder | C96346 | 1
LED_RED | D5 | LED_0805_2012Metric_Pad1.15x1.40mm_HandSolder | C965812 | 1

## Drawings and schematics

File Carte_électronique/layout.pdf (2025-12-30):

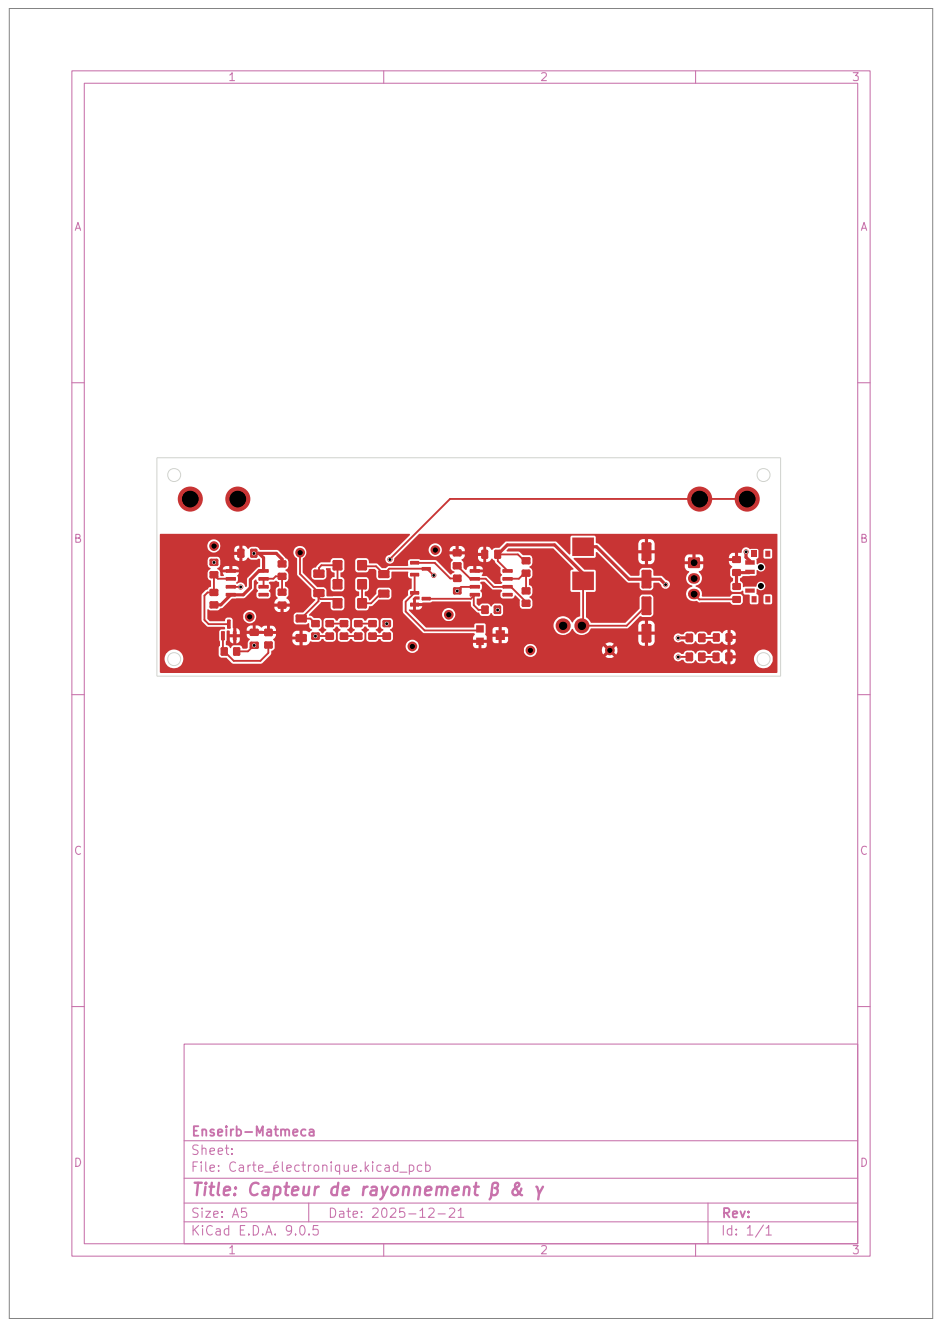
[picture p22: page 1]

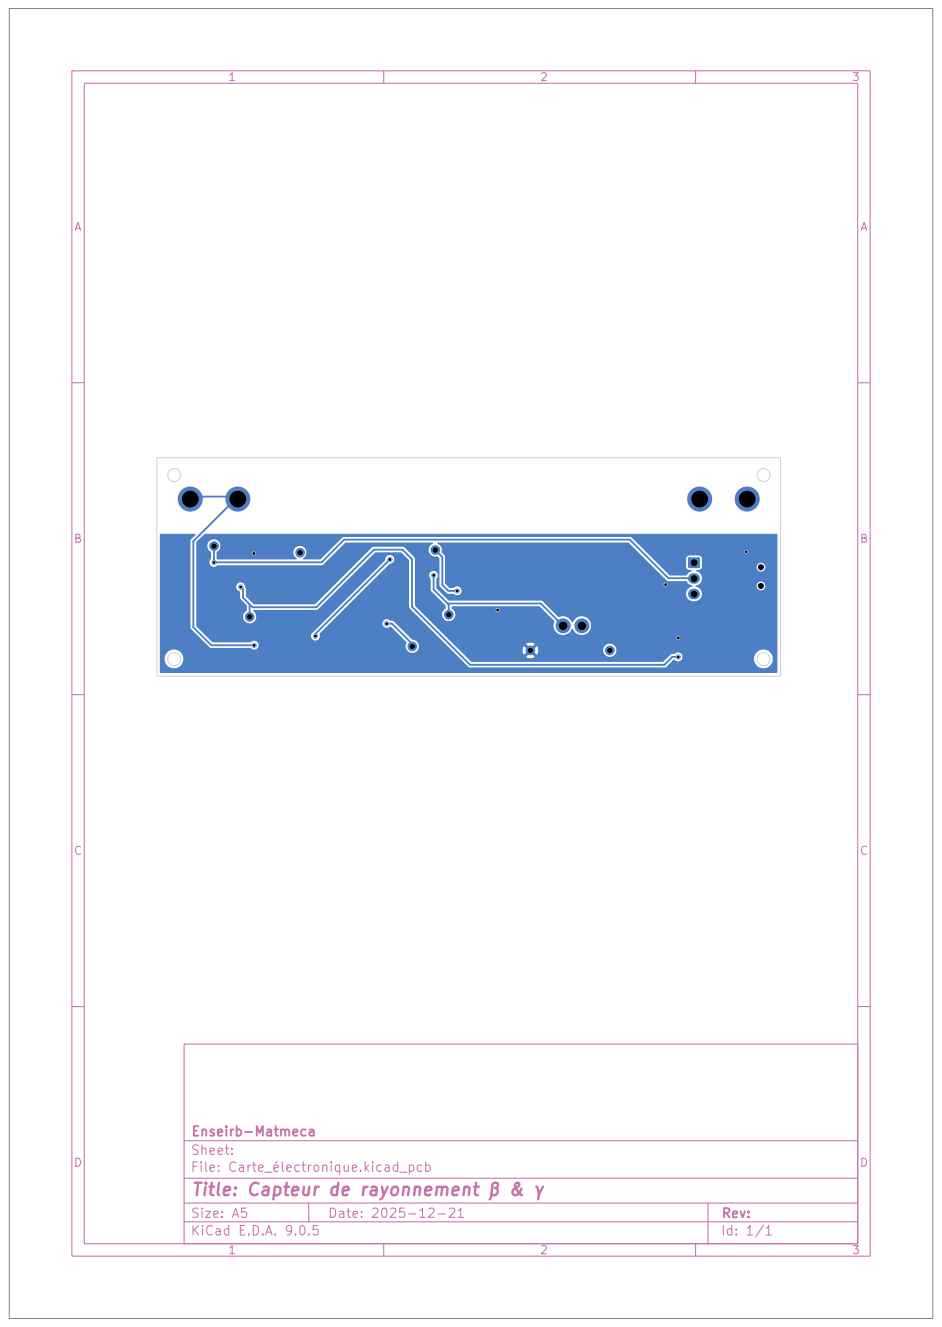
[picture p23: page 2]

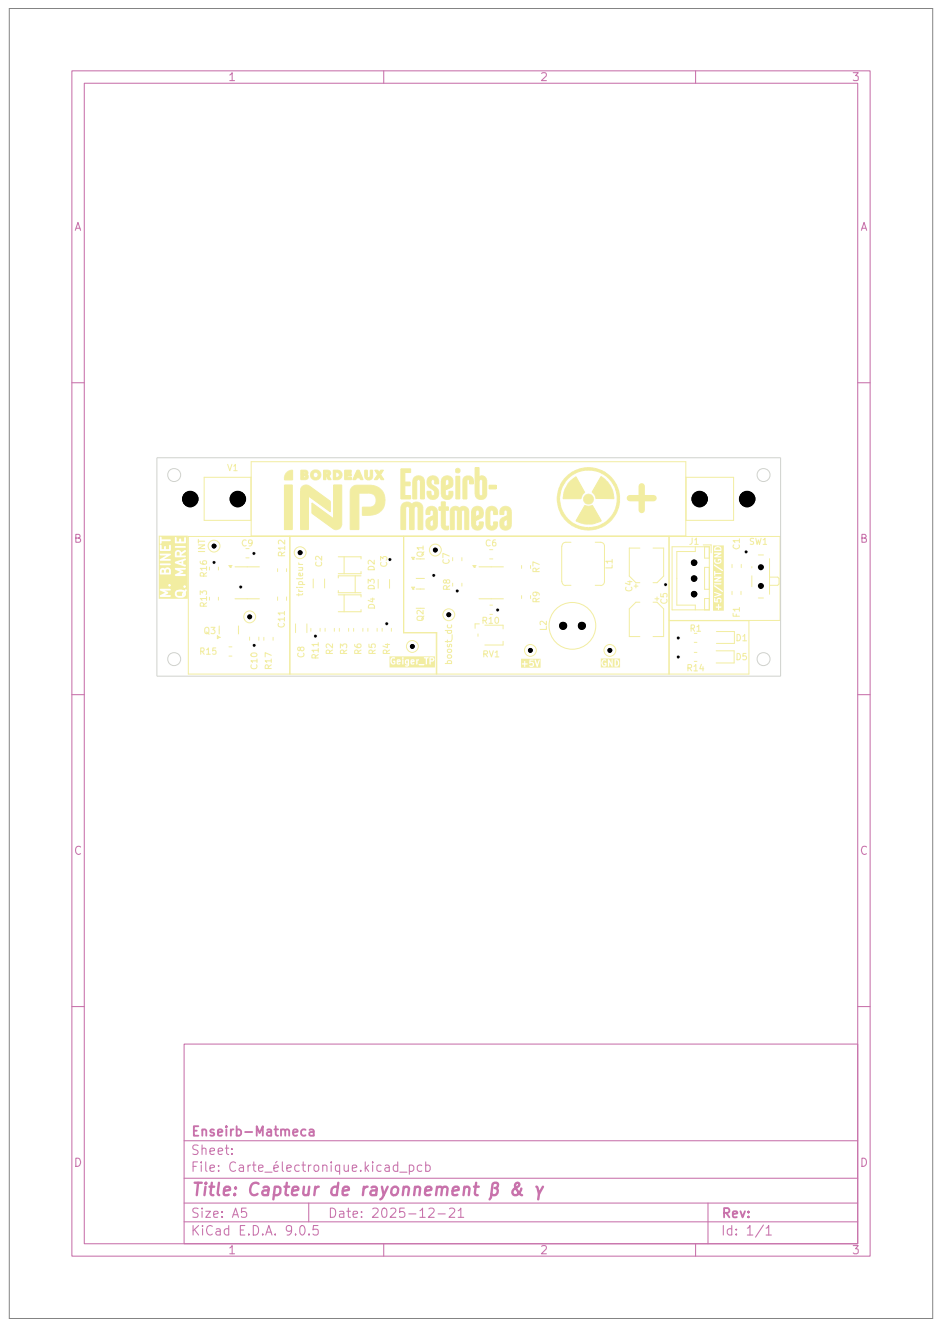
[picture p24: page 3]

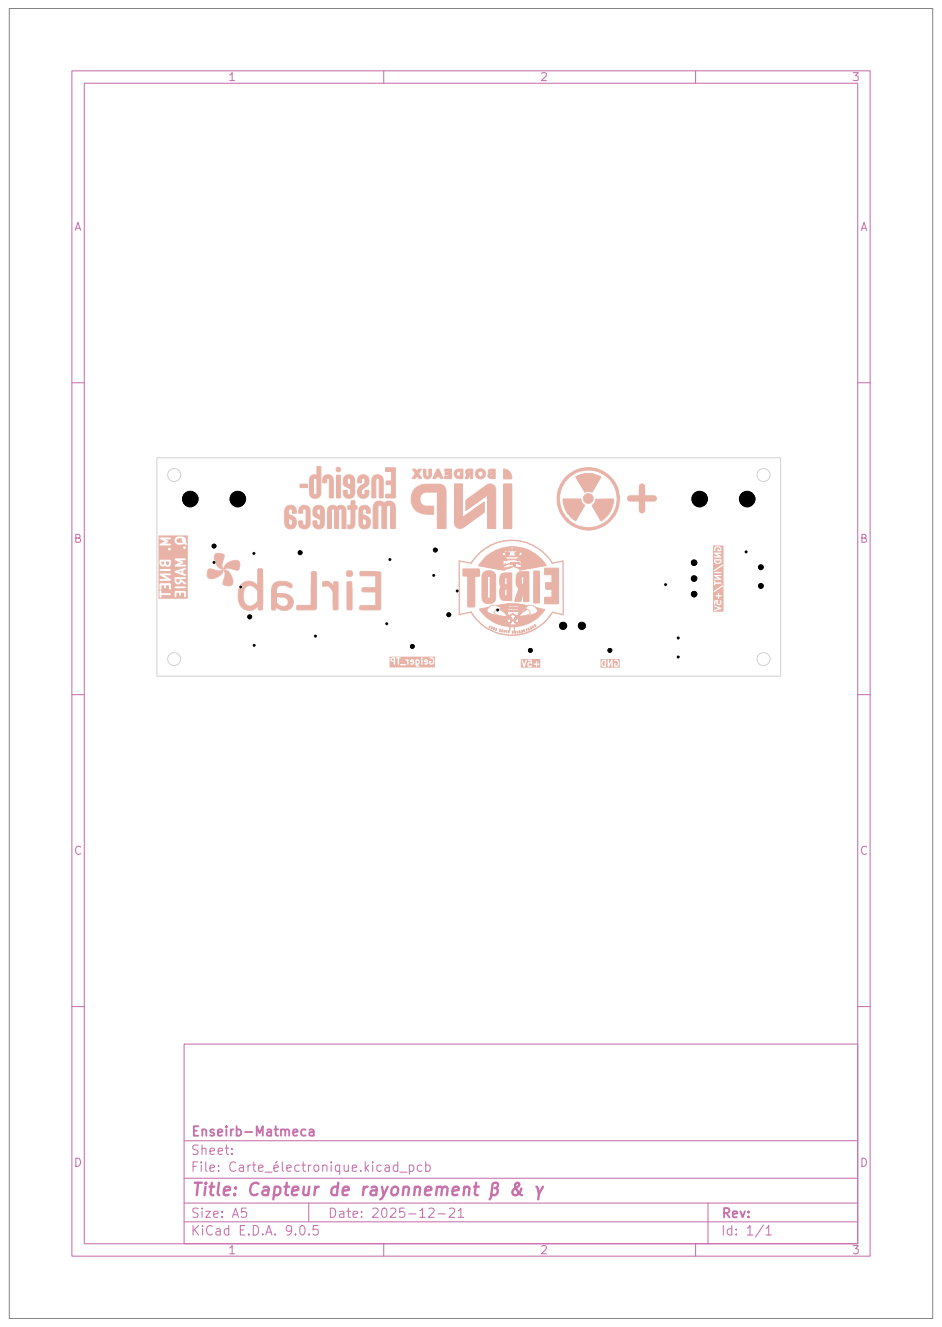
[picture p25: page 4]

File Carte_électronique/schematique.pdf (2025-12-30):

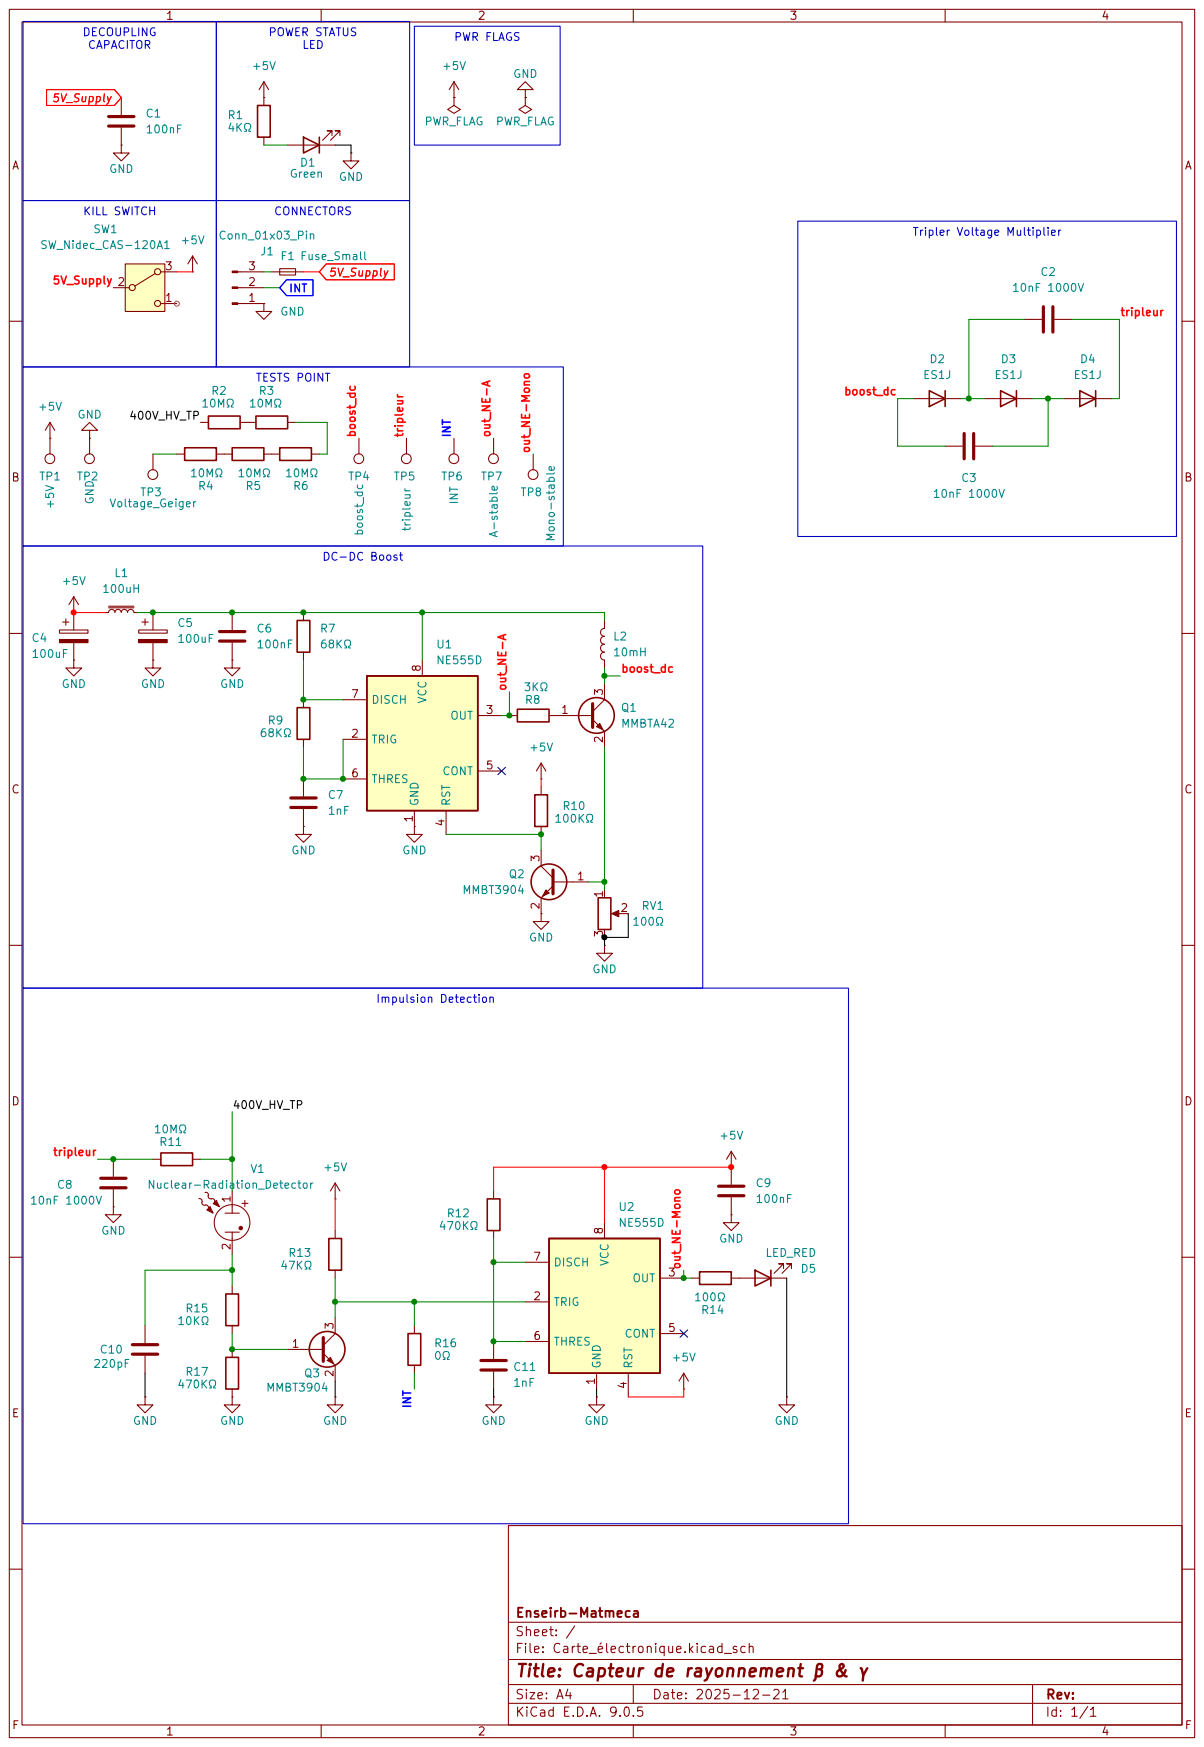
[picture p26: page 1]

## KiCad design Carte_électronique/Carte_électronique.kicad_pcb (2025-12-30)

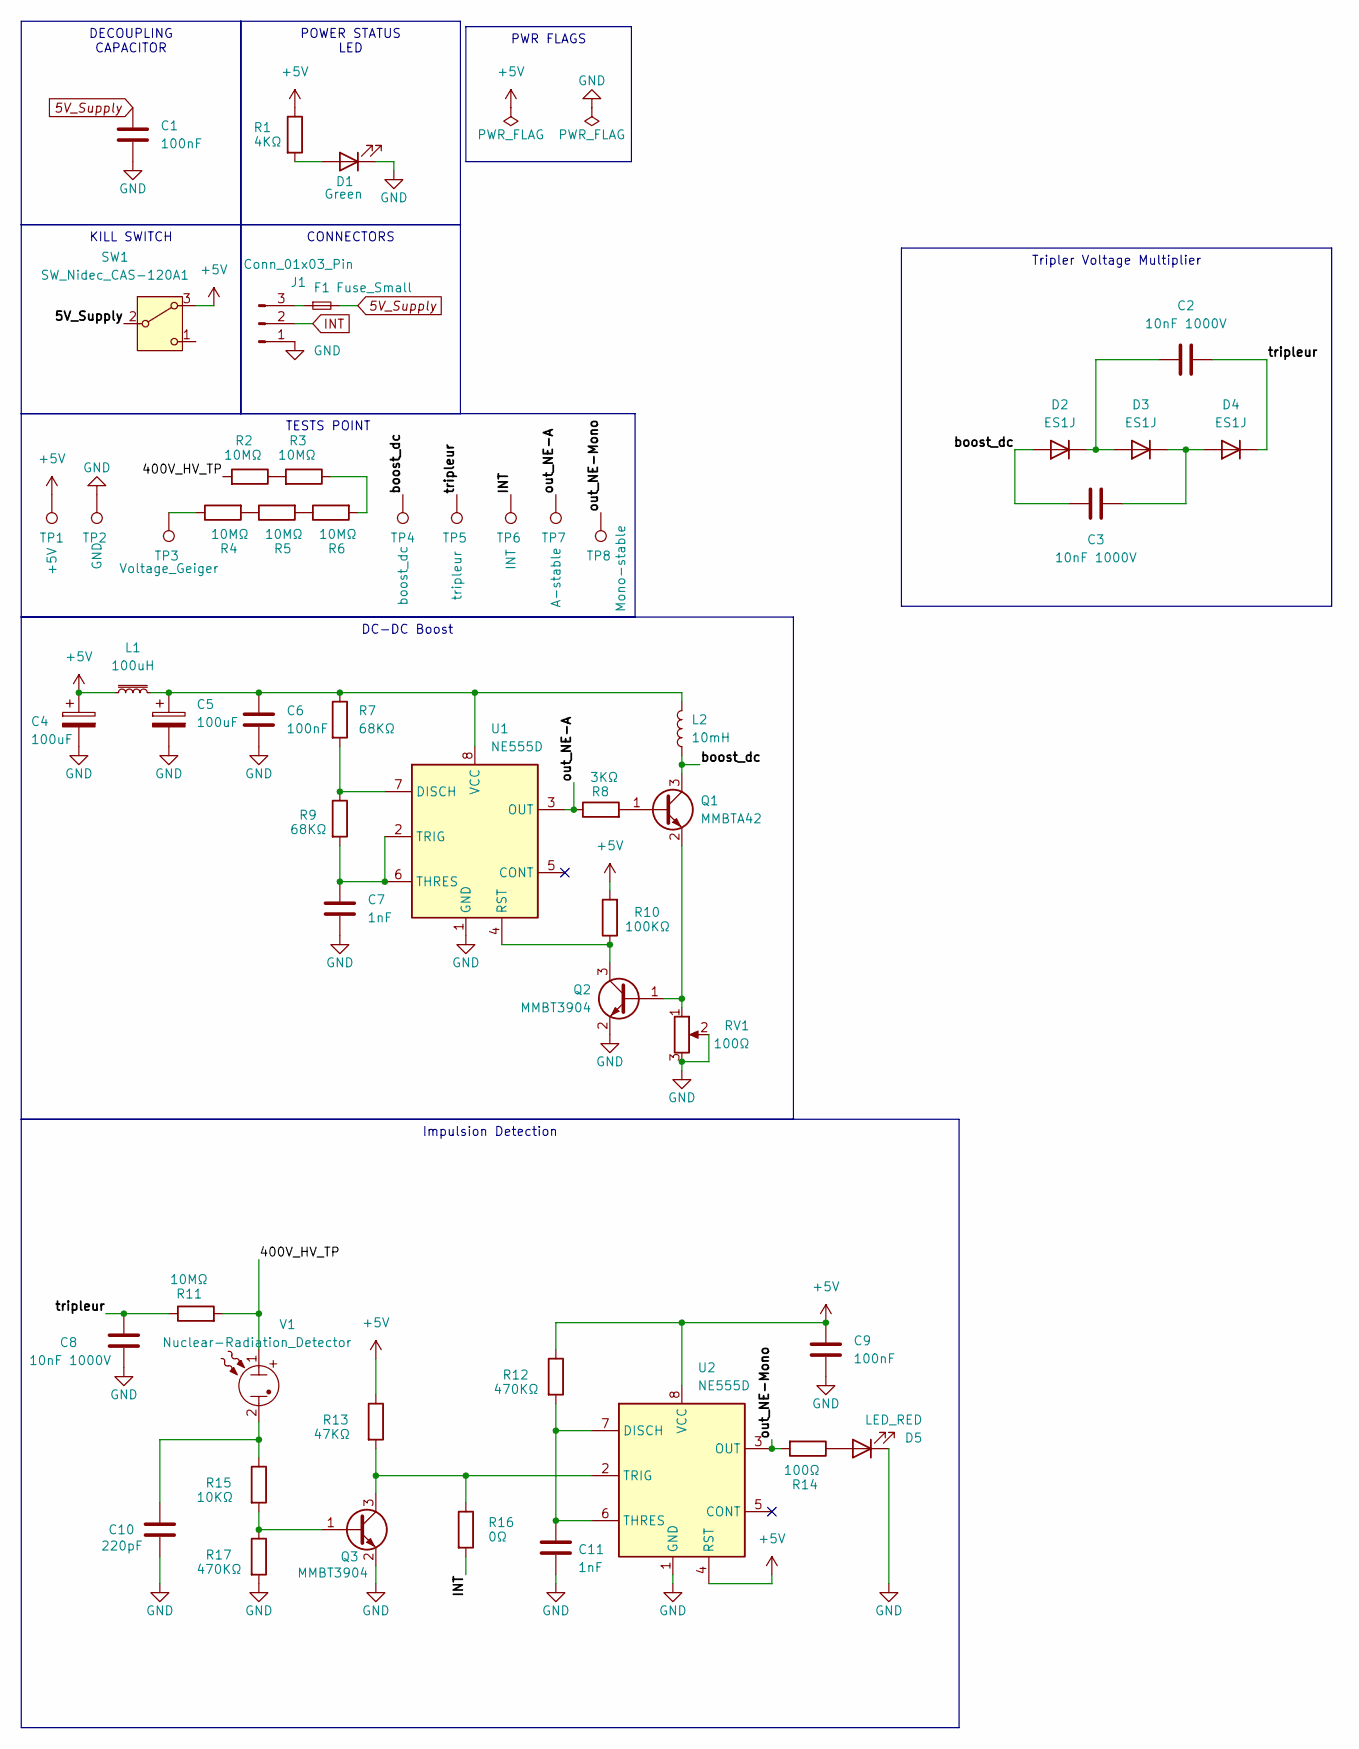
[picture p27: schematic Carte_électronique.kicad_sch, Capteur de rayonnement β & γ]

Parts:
C1, C6, C9: 100nF; C_0805_2012Metric_Pad1.18x1.45mm_HandSolder
C2, C3, C8: 10nF 1000V; C_1206_3216Metric_Pad1.33x1.80mm_HandSolder
C4, C5: 100uF; CP_Elec_5x5.3; Manufacturer PN UWT0J102MNL1GS; LCSC C445083
C7, C11: 1nF; C_0805_2012Metric_Pad1.18x1.45mm_HandSolder
C10: 220pF; C_0805_2012Metric_Pad1.18x1.45mm_HandSolder
D1: Green; LED_0805_2012Metric_Pad1.15x1.40mm_HandSolder; Manufacturer PN 151031VS06000
D2, D3, D4: ES1J; D_SMAF
D5: LED_RED; LED_0805_2012Metric_Pad1.15x1.40mm_HandSolder
F1: Fuse_Small; Fuse_0805_2012Metric_Pad1.15x1.40mm_HandSolder
J1: Conn_01x03_Pin; JST_XH_B3B-XH-A_1x03_P2.50mm_Vertical
L1: 100uH; L_Bourns_SRP7028A_7.3x6.6mm
L2: 10mH; L_Radial_D7.2mm_P3.00mm_Murata_1700
Q1: MMBTA42; D_SOT-23
Q2, Q3: MMBT3904; D_SOT-23
R1: 4KΩ; R_0805_2012Metric_Pad1.20x1.40mm_HandSolder; Manufacturer PN 0603WAF4700T5E; LCSC C23179
R2, R3, R4, R5, R6, R11: 10MΩ; R_0805_2012Metric_Pad1.20x1.40mm_HandSolder
R7, R9: 68KΩ; R_0805_2012Metric_Pad1.20x1.40mm_HandSolder
R8: 3KΩ; R_0805_2012Metric_Pad1.20x1.40mm_HandSolder
R10: 100KΩ; R_0805_2012Metric_Pad1.20x1.40mm_HandSolder
R12, R17: 470KΩ; R_0805_2012Metric_Pad1.20x1.40mm_HandSolder
R13: 47KΩ; R_0805_2012Metric_Pad1.20x1.40mm_HandSolder
R14: 100Ω; R_0805_2012Metric_Pad1.20x1.40mm_HandSolder
R15: 10KΩ; R_0805_2012Metric_Pad1.20x1.40mm_HandSolder
R16: 0Ω; R_0805_2012Metric_Pad1.20x1.40mm_HandSolder
RV1: 100Ω; Potentiometer_Bourns_TC33X_Vertical
SW1: SW_Nidec_CAS-120A1; SW_SPDT_PCM12
TP1: +5V; TestPoint_THTPad_D1.5mm_Drill0.7mm
TP2: GND; TestPoint_THTPad_D1.5mm_Drill0.7mm
TP3: Voltage_Geiger; TestPoint_THTPad_D1.5mm_Drill0.7mm
TP4: boost_dc; TestPoint_THTPad_D1.5mm_Drill0.7mm
TP5: tripleur; TestPoint_THTPad_D1.5mm_Drill0.7mm
TP6: INT; TestPoint_THTPad_D1.5mm_Drill0.7mm
TP7: A-stable; TestPoint_THTPad_D1.5mm_Drill0.7mm
TP8: Mono-stable; TestPoint_THTPad_D1.5mm_Drill0.7mm
U1, U2: NE555D; SOIC-8_3.9x4.9mm_P1.27mm
V1: Nuclear-Radiation_Detector; Tube_Geiger_J305

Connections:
5V_Supply: C1.1, F1.2, SW1.2 (B)
+5V: C4.1, C9.1, L1.1, R1.1, R10.2, R12.1, R13.1, SW1.3 (A), TP1.1, U2.4 (RST), U2.8 (VCC)
/400V_HV_TP: R2.2, R11.2, V1.1
/boost_dc: C3.2, D2.2 (A), L2.1, Q1.3 (C), TP4.1
/out_NE-A: R8.1, TP7.1, U1.3 (OUT)
/out_NE-Mono: R14.2, TP8.1, U2.3 (OUT)
/tripleur: C2.2, C8.1, D4.1 (K), R11.1, TP5.1
GND: C1.2, C4.2, C5.2, C6.2, C7.2, C8.2, C9.2, C10.2, C11.2, D1.1 (K), D5.1 (K), J1.1, Q2.2 (E), Q3.2 (E), R17.2, RV1.2, RV1.3, TP2.1, U1.1 (GND), U2.1 (GND)
INT: J1.2, R16.2, TP6.1
unnamed: C10.1, R15.1, V1.2
unnamed: D1.2 (A), R1.2
unnamed: C2.1, D2.1 (K), D3.2 (A)
unnamed: C3.1, D3.1 (K), D4.2 (A)
unnamed: D5.2 (A), R14.1
unnamed: F1.1, J1.3
unnamed: Q1.1 (B), R8.2
unnamed: Q1.2 (E), Q2.1 (B), RV1.1
unnamed: Q2.3 (C), R10.1, U1.4 (RST)
unnamed: Q3.1 (B), R15.2, R17.1
unnamed: Q3.3 (C), R13.2, R16.1, U2.2 (TRIG)
unnamed: R2.1, R3.2
unnamed: R3.1, R6.2
unnamed: R4.1, TP3.1
unnamed: R4.2, R5.1
unnamed: R5.2, R6.1
unnamed: R7.2, R9.1, U1.7 (DISCH)
unnamed: C7.1, R9.2, U1.2 (TRIG), U1.6 (THRES)
unnamed: C5.1, C6.1, L1.2, L2.2, R7.1, U1.8 (VCC)
unnamed: C11.1, R12.2, U2.6 (THRES), U2.7 (DISCH)

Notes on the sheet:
Impulsion Detection
DC-DC Boost
KILL SWITCH
TESTS POINT
PWR FLAGS
Tripler Voltage Multiplier
DECOUPLING CAPACITOR
POWER STATUS LED
CONNECTORS

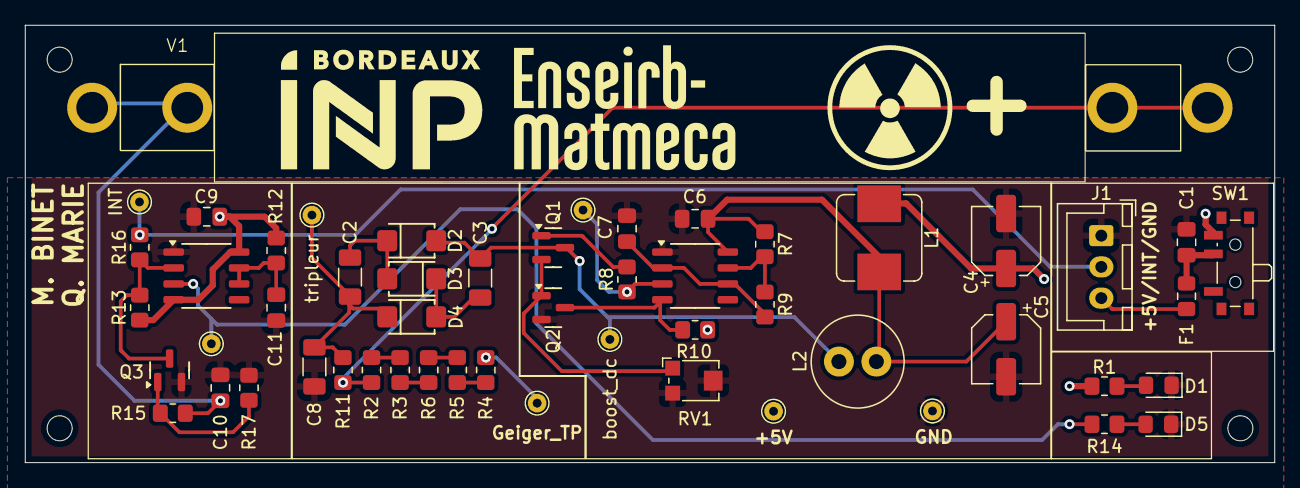
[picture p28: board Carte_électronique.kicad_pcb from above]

Board: 2 copper layers, 100.0 x 35.0 mm, 53 parts (0 on the bottom side), 29 nets.

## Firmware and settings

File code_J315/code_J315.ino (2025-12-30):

/*
   Geiger Counter - PPS only
   Arduino Nano
   Affichage du nombre d'impulsions sur la dernière seconde (PPS)
*/

#define GEIGER_PIN 2   // D2 = INT0 sur Arduino Nano

volatile unsigned long pulseCount = 0;

unsigned long lastSecond = 0;
unsigned long pps = 0;

void geigerISR() {
  pulseCount++;   // Une impulsion détectée
}

void setup() {
  Serial.begin(115200);
  while (!Serial);

  Serial.println("Geiger Counter - PPS mode");

  pinMode(GEIGER_PIN, INPUT_PULLUP);
  attachInterrupt(digitalPinToInterrupt(GEIGER_PIN), geigerISR, FALLING);

  lastSecond = millis();
}

void loop() {

  if (millis() - lastSecond >= 1000) {

    noInterrupts();
    pps = pulseCount;
    pulseCount = 0;
    interrupts();

    // Affichage PPS
    Serial.print("PPS = ");
    Serial.println(pps);

    lastSecond += 1000;
  }
}
